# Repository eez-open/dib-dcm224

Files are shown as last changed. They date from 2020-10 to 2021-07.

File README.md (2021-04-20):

### Ownership and License
The contributors are listed in CONTRIB.TXT.

Licenses | OSHWA UID
--|--
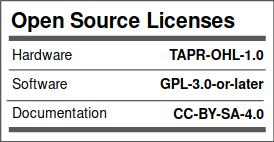
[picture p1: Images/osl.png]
osl
 | OSHW-HR000007 (https://certification.oshwa.org/hr000007.html)

### Overview

The EEZ DIB DCM224 Power module features dual sync buck converters based on [LT3763](https://www.analog.com/en/products/lt3763.html) with programmable output voltage, PWM dimming and current limit.

### r3B2 prototype

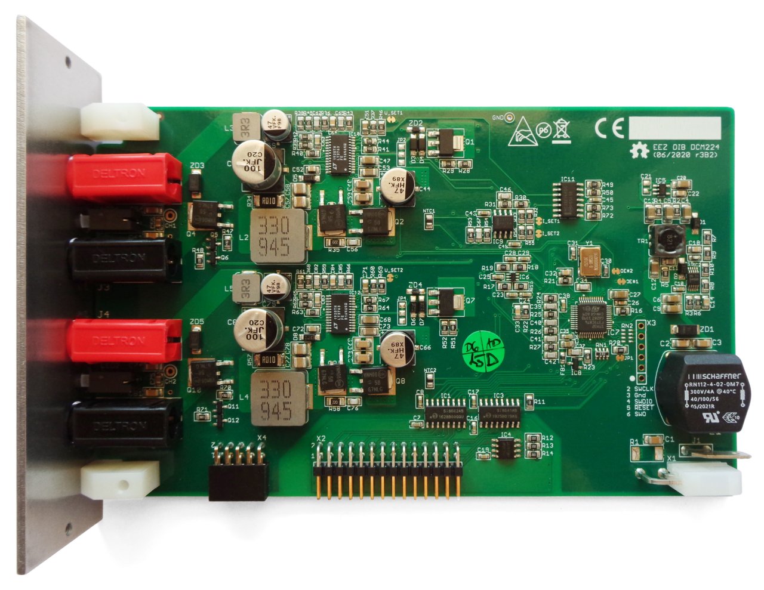
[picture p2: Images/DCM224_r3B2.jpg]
module


### Feature list
- On-board STM32F373 MCU
Power input: 48 Vdc (e.g. Mean Well LRS-150F-48)
- Combined max. output power: up to 155 W
- Separate control of each power outputs
- Voltage regulation (CV), 1 – 24 V. Voltage set resolution (_U_SET_): 12-bit, read resolution (_U_MON_): 15-bit
- Current regulation (CC), up to 4.9 A. Current set resolution (_I_SET_): 12-bit, read resolution (_I_MON_): 15-bit
- PWM LED dimming
- MCU generated two counterphase switching frequencies
- On-board power pre-regulator and bias power supply
- Output Enable (_OE_) and Constant Current mode (_CC_) LED indications
- Output LC filter for improved ripple and noise
- On-board 4 mm power output terminals with standard (19.05 mm) pitch
- Pass-thru connector for Vout- coupling with other DIB power modules
- Galvanically isolated SPI bus for communication with [MCU board](https://github.com/eez-open/modular-psu/tree/master/mcu)
- I2C EEPROM for storing board specific configuration and calibration parameters
- Dimensions: 155 x 95 mm, 4-layer PCB
- **CE certified design**

### Firmware repository

https://github.com/eez-open/dib-dcm224-fw  
The firmware download procedure is described in Chapter 13.2 of the [User Manual](https://www.envox.eu/eez-bench-box-3/bb3-user-manual/13-firmware-upgrade/#bb3_man_module_upgrade).

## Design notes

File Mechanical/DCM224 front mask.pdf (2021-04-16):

# DCM224

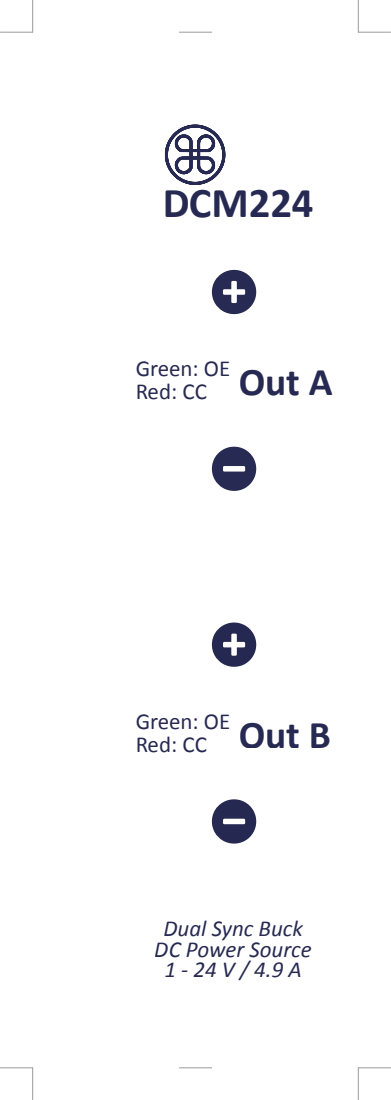
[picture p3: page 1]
Green: OE Red: CC; Out B; Out A

Dual Sync Buck
DC Power Source

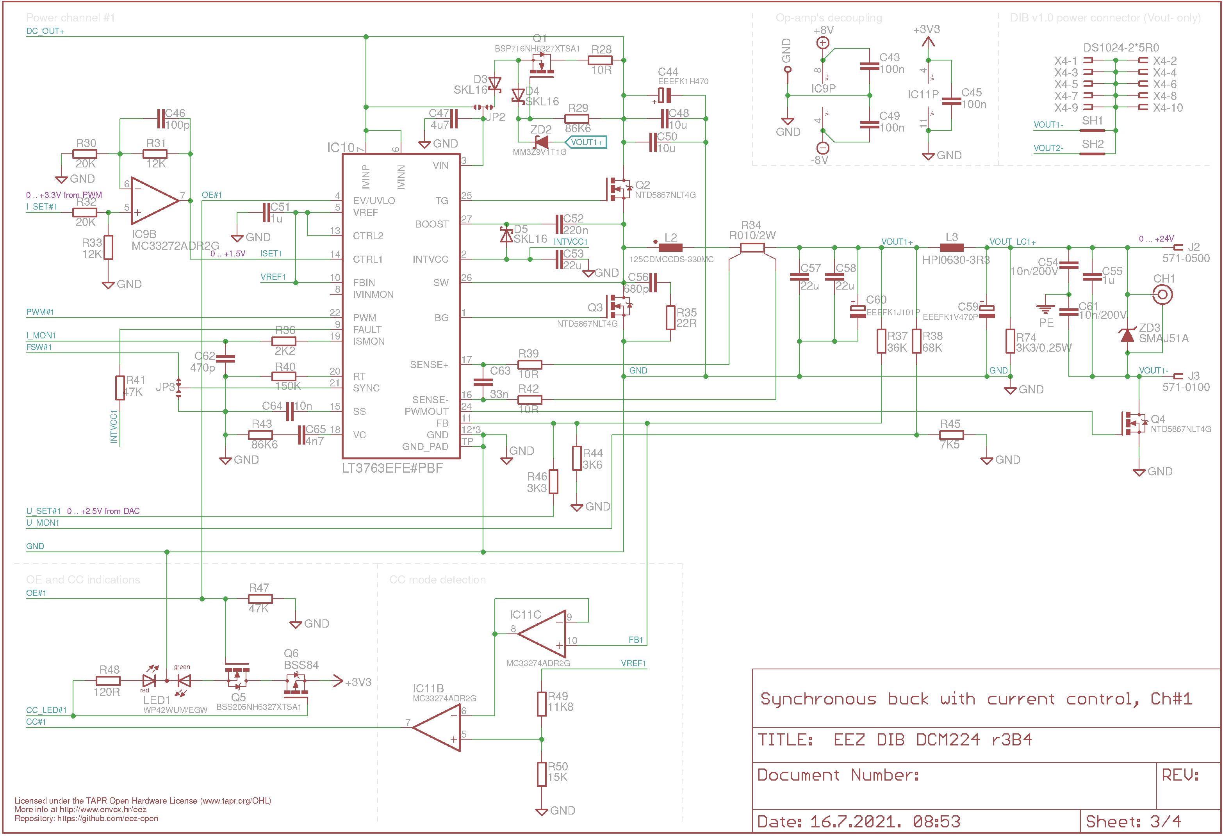
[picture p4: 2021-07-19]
EEZ DIB DCM224 r3B4 Sheet3of4.png

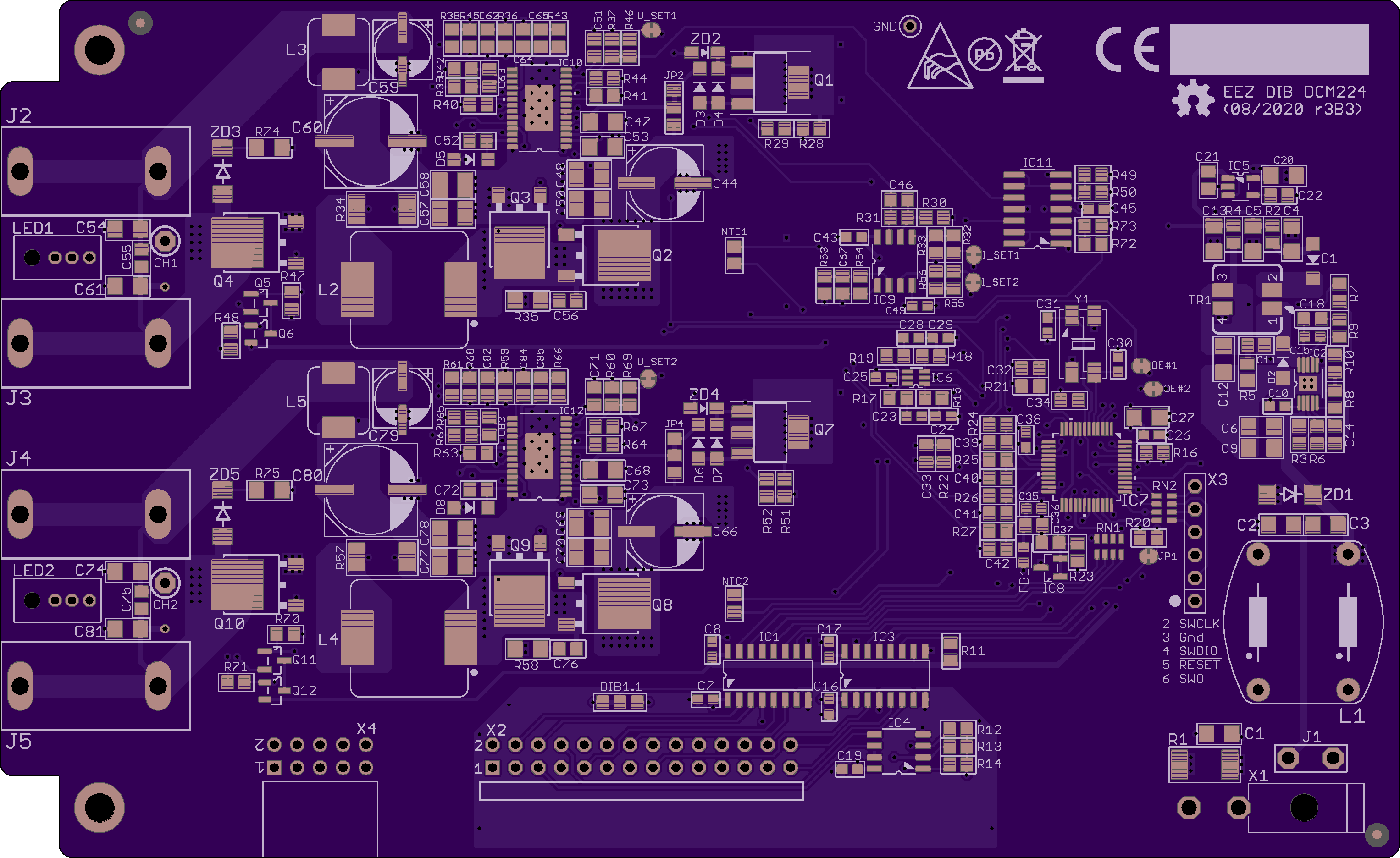
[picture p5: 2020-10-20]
Images/EEZ_DIB_DCM224_PCB_top.png

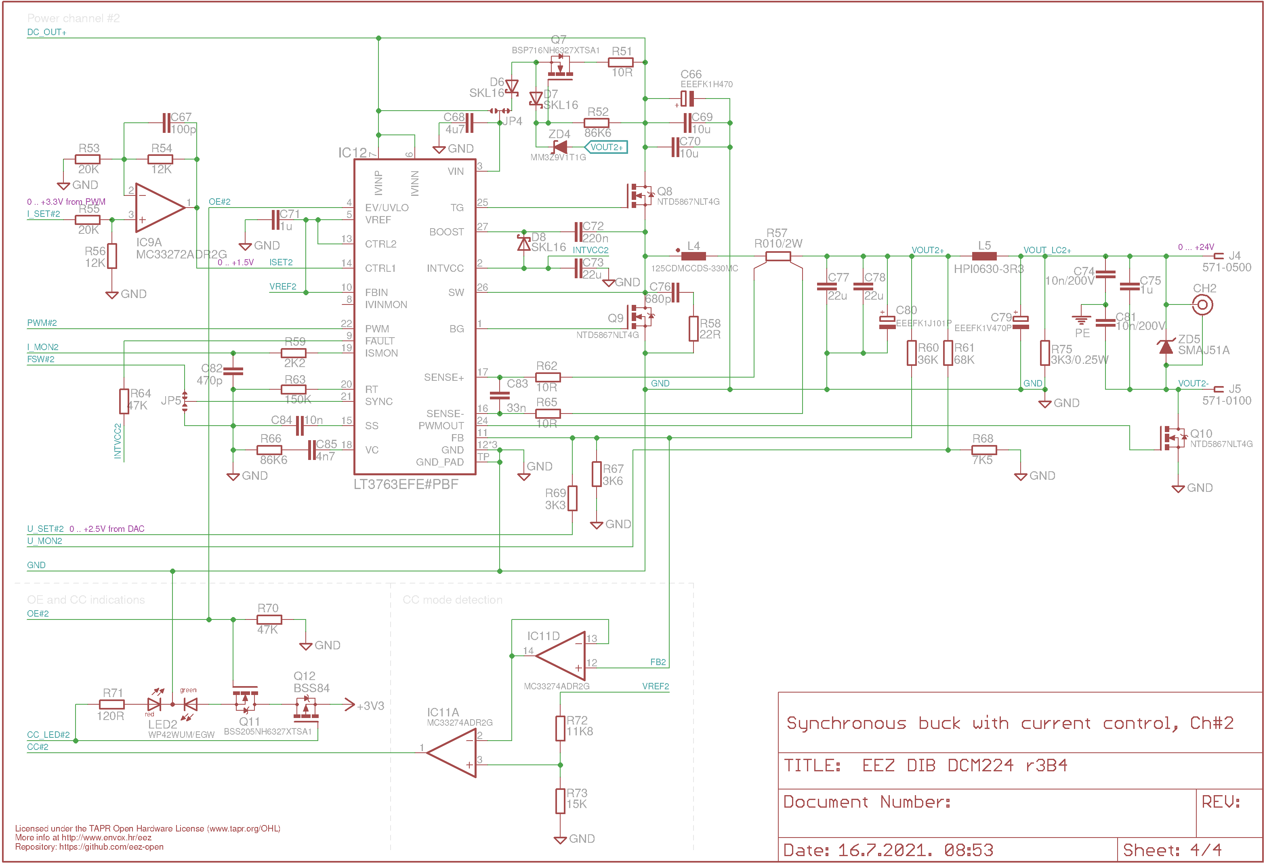
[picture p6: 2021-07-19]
EEZ DIB DCM224 r3B4 Sheet4of4.png

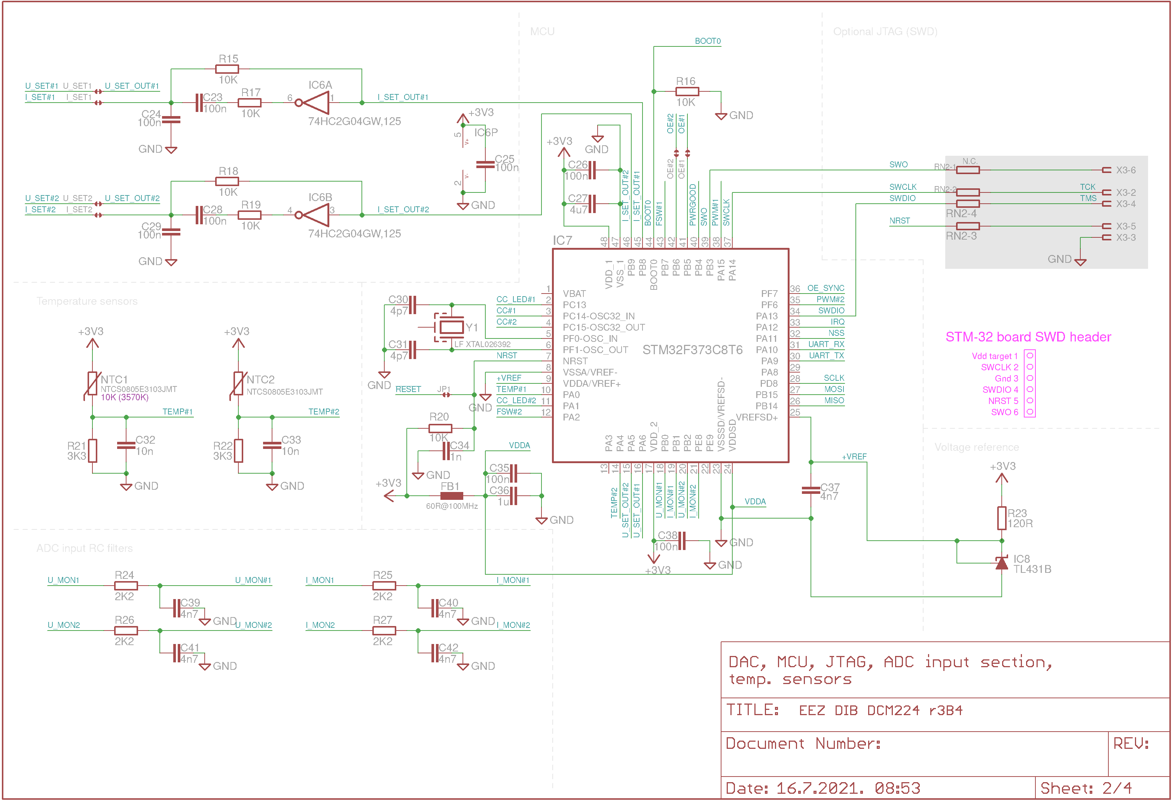
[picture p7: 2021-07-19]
EEZ DIB DCM224 r3B4 Sheet2of4.png

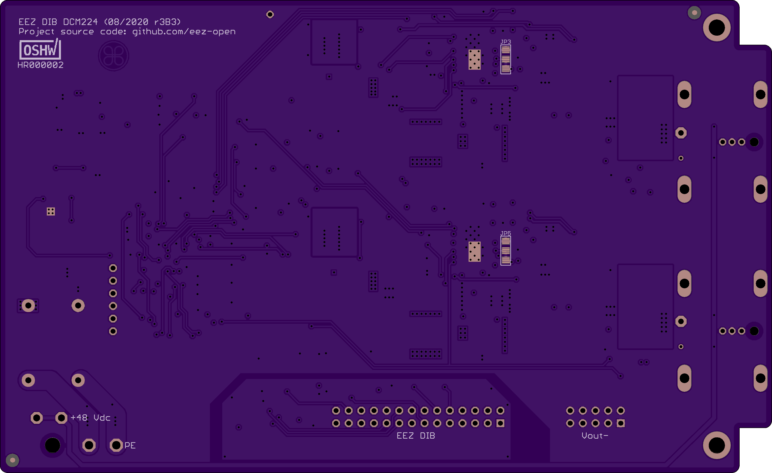
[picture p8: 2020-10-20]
Images/EEZ_DIB_DCM224_PCB_bottom.png

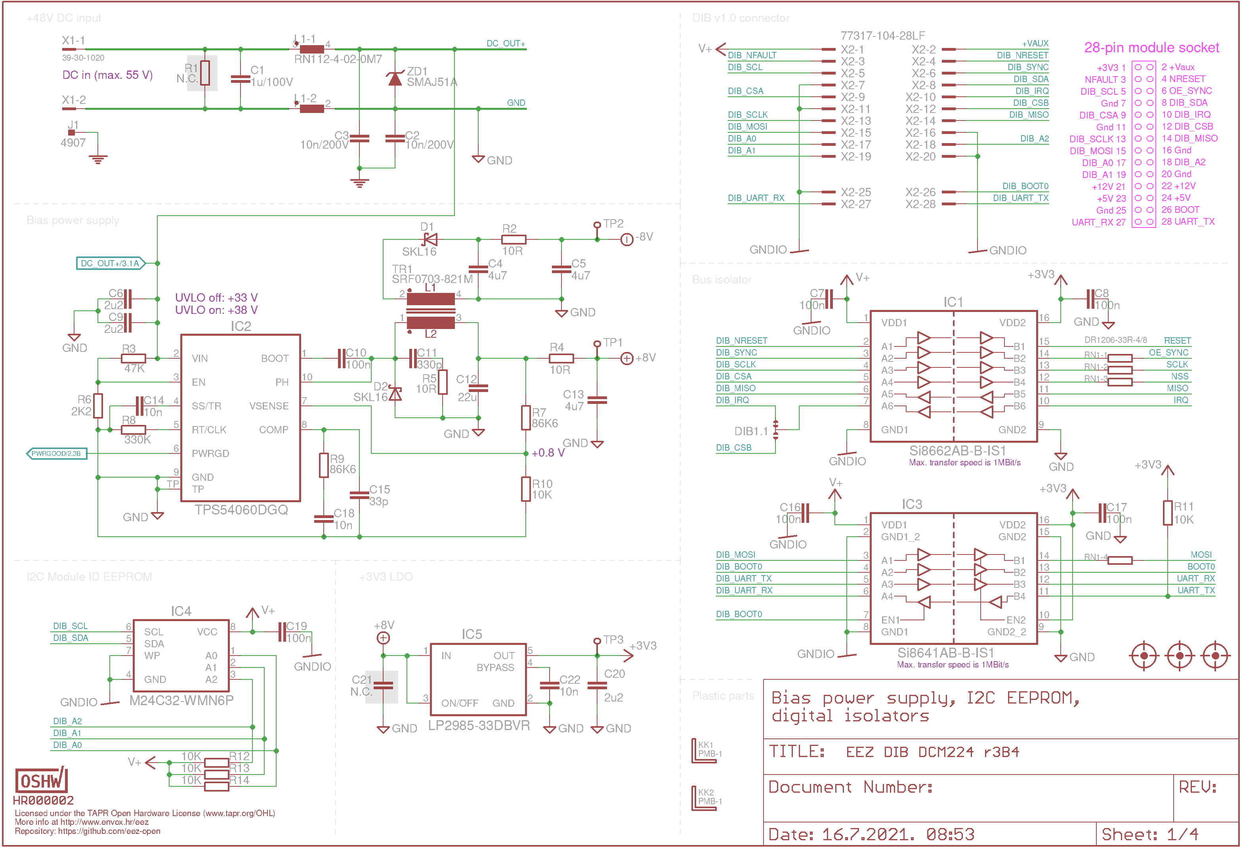
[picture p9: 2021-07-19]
EEZ DIB DCM224 r3B4 Sheet1of4.png

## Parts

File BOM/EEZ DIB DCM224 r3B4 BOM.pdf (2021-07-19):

EEZ DIB DCM224 BOM (r3B4, 2021-07-19) Project source code at https://github.com/eez-open/modular-psu
Farnell / Element14 Unit price # Qty Part name Package Reference designator Code Part Number MOQ € | Digi-Key Unit price Part Number MOQ € | Mouser Unit price Part Number MOQ €
| | 810-C3216X7R2A105 M
C0805C331J5GAC TU | | 80-C0805C331J5G
| | 963-LMK316ABJ226 ML-T
C14, C18, C22, C32, C33, VJ0805Y103JXXP C64, C84 W1BC | | 710-885012207122
| | C0805C330K5G ACTU 603-C1206KRX7RAB B103
C30, C31 MC0603N4R7C500 CT | | 710-885012006049
| | 710-885012007040
VJ0805Y105KXXT W1BC | | 603-CC805MKX7R7B B105
| | 810-C2012C0G1H47 2J-1
C3216X7R1E475K 160AC | | 963-EMK316B7475M L-T
| | FK1H470P
C46, C67 C0805C101JAGAC TU | | 80-C0805C101K5G
| | 810-C3216X7R1HK1 60AC
MC0805B224J250 CT | | 963-EMK212B7224K G-T
| | 710-885012207085
C57, C58, C77, C78 MC1210X226K250 CT | | 603-CC121KKX7R8B B226
| | FK1V470P
C1206C225K5REC TU | | 80-C1206C225M5R ECLR
1 | 1 1u/100V | 1206 | C1 | 2579026 | 0,635 | 5 | 311-1948-6-ND | 0,271 | 10 | 0,227 10
2 | 1 330p | C0G, 0805 | C11 | 1414686 | 0,054 10 | 1276-1189-1-ND | 0,049 | 10 | 0,036 10
3 | 3 22u | 1206, 10V | C12, C53, C73 | 2112754 | 0,616 | 5 | 1276-1287-1-ND | 0,265 | 10 | 0,155 10
4 | 7 10n | 0805 | 2896555 | 0,065 10 | 490-7194-1-ND | 0,017 | 10 | 0,036 10
5 | 1 33p | C0G, 0603 | C15 | 1759197 | 0,042 10 | 1276-1105-1-ND | 0,048 | 10 | 0,036 10
6 | 6 10n/200V | 1206 | C2, C3, C54, C61, C74, C81 2812560 | 885342207005 | 0,078 | 5 | 311-4491-1-ND | 0,150 | 10 | 0,129 10
7 | 2 4p7 | C0G, 0603 | 2627469 | 0,329 10 | 311-1740-1-ND | 0,054 | 10 | 0,072 10
8 | 1 1n | 0805 | C34 | 2896470 | 0,044 10 | 732-7858-1-ND | 0,055 | 10 | 0,052 10
9 | 5 1u | 0805 | C36, C51, C55, C71, C75 | 2896566 | 0,084 | 5 | 587-1283-1-ND | 0,090 | 10 | 0,062 10
10 | 7 4n7 | C0G, 0805 | 1828942 | 0,184 10 | 732-12255-1-ND | 0,162 | 10 | 0,072 10
11 | 6 4u7 | 1206 | C4, C5, C13, C27, C47, C68 1907356 | 0,240 | 5 | 1276-2970-1-ND | 0,199 | 10 | 0,129 10
12 | 2 EEEFK1H470 | | 9695931 | EEEFK1H470P | 0,419 | 1 | PCE3815CT-ND | 0,590 | 1 | 0,524 | 1
13 | 2 100p | C0G, 0805 | 2896861 | 0,023 10 | 399-15000-1-ND | 0,019 | 10 | 0,032 10
14 | 4 10u | 1210, 50V | C48, C50, C69, C70 | 2672214 | 0,684 | 5 | 1276-6736-1-ND | 0,184 | 10 | 0,597 10
15 | 2 220n | 0805 | C52, C72 | 2320828 | 0,087 | 5 | 1276-6477-1-ND | 0,520 | 10 | 0,059 10
16 | 2 680p | 0805 | C56, C76 | 2524913 | 0805B681K500CT | 0,049 10 | 1276-2538-1-ND | 0,049 | 10 | 0,036 10
17 | 4 22u | 1210, 25V | 2320935 | 1,490 | 1 | 1276-3373-1-ND | 0,369 | 10 | 0,777 10
18 | 2 | C59, C79 | 9695850 | | 0,368 | 1 | PCE3842CT-ND | 0,460 | 1 | 0,445 | 1
19 | 3 2u2 | 1206, 50V | C6, C9, C20 | 2991428 | 0,181 | 5 | 1276-2723-1-ND | 0,132 | 10 | 0,106 10
20 | 2 EEEFK1J101P | C60, C80 | 9696040 | EEEFK1J101P | 1,020 | 1 | PCE3819CT-ND | 0,780 | 1 | 0,690 | 1

C1206X105K1RAC
AUTO

MC1206X226M100
CT

MC0805N330J500
CT

VJ0805A102JXAC
W1BC

C37, C39, C40, C41, C42,
C65, C85

GRM2165C1H472J
A01D
Ø8mm, low ESR | C44, C66 | 667-EEE-

GRT31CR61H106
KE01L
EEEFK1V470P | Ø8mm, low ESR | EEEFK1V470P | 667-EEE-
Ø10mm, low ESR | 667-EEE- FK1J101P

# Qty Part name | RS Components | TME | Technology | Price calculation for 1 set

Unit price Code Part Number MOQ € | Unit price Code / Part Number MOQ € | THT SMD | | | Line Cost €

1 1 1u/100V

2 1 330p

3 3 22u

4 7 10n

5 1 33p

6 6 10n/200V

7 2 4p7

8 1 1n

9 5 1u

10 7 4n7

11 6 4u7

12 2 EEEFK1H470

13 2 100p

14 4 10u

15 2 220n

16 2 680p

17 4 22u

18 2

19 3 2u2

20 2 EEEFK1J101P

EEEFK1V470P

136-4396 | 0,294 50 | - | 1 | Mouser | 0,227 € | 1 | 0,227
176-3198 | 0,037 200 | CL21C331JBANNNC | 0,029 100 | 1 | TME | 0,029 € | 1 | 0,029
172-1532 | 0,095 50 | CL31A226MOCLNNC | 0,083 100 | 3 | TME | 0,083 € | 3 | 0,250
464-6672 | 0,026 50 | CC0805KRX7R9103 | 0,027 100 | 7 | Digikey | 0,017 € | 7 | 0,119
264-4264 | 0,069 25 | CL21C330JBANNNC | 0,015 100 | 1 | TME | 0,015 € | 1 | 0,015
669-8647 | 0,128 25 | 0,019 100 | 6 | TME | 0,019 € | 6 | 0,114
298-9315 | 0,024 25 | CL10C4R7CB8NNNC | 0,024 100 | 2 | RS | 0,024 € | 2 | 0,048
723-6408 | 0,031 100 | CL21C102JBCNNNC | 0,026 100 | 1 | TME | 0,026 € | 1 | 0,026
451-5770 | 0,028 25 | CL21B105KOFNNNE | 0,010 100 | 5 | TME | 0,010 € | 5 | 0,052
741-4529 | 0,056 100 | 0,021 100 | 7 | TME | 0,021 € | 7 | 0,147
691-1221 | 0,232 25 | 0,381 10 | 6 | Mouser | 0,129 € | 6 | 0,774
537-0590 EEEFK1H470P | 0,510 | 5 | EEEFK1H470P | 0,183 | 5 | 2 | TME | 0,183 € | 2 | 0,366
461-3997 | 0,030 50 | CL21C101JBANNNC | 0,026 100 | 2 | Digikey | 0,019 € | 2 | 0,038
103-4163 | 0,236 20 | CL31A106KBHNNNE | 0,546 10 | 4 | Digikey | 0,184 € | 4 | 0,736
103-4126 | 0,039 50 | CL21B224KAFNNNE | 0,022 100 | 2 | TME | 0,022 € | 2 | 0,044
- | CL21C681JBCNNNC | 0,048 100 | 2 | Mouser | 0,036 € | 2 | 0,072
766-1182 | 0,343 10 | CL32A226KAJNNNE | 0,158 10 | 4 | TME | 0,158 € | 4 | 0,632
537-0657 EEEFK1V470P | 0,422 | 1 | EEEFK1V470P | 0,130 | 5 | 2 | TME | 0,130 € | 2 | 0,260
184-3509 | 0,151 10 | CL31B225KBHNNNE | 0,029 50 | 3 | TME | 0,029 € | 3 | 0,086
708-3623 EEEFK1J101P | 0,676 | 5 | EEEFK1J101P | 0,321 | 5 | 2 | TME | 0,321 € | 2 | 0,642

Best
Supplier

Lowest
unit price
€

Order
Qty

12061C105KAT
2A

0805N331J500C
T
LMK316ABJ226
KL

08055C103KAT 2A

| VJ1206Y103KXCTW1 BC

C0603C479C5G ACTU

C0805C330J5G
ACTU
CC1206KRX7R
ABB103

GRM2195C1H1
02JA01D
C0805C105K4R ACTU
| GRM2165C1H472JA0 1D
C1206C475K3R ACTU | GCM31CR71E475KA5 5L

C2012C0G1H47
2J060AA

CC0805JRNP09
BN101
UMK316BBJ106
KL-T

UMK212B7224K
G-T

CL32A226KAJN
NNE

UMK316B7225K
LHT

# Qty Part name Package Reference designator Code Part Number MOQ € | Part Number Unit price MOQ € | Part Number Unit price MOQ Unit price €

MC0805N471J500 CT | | 710-885012007038
| | 710-885012207069
C7, C8, C10, C16, C17, C19, C0603C104K4RAC C23, C24, C25, C26, C28, 7081 C29, C35, C38, C43, C45, C49 | | 80-C0603C104M4R
| RB160MM-60CT-ND | 755-RB160MM-60TR
BLM18AG102SN1 D | | 81-BLM18AG102SH 1D
| SI8662AB-B-IS1-ND | 634-SI8662AB-B-IS1
| LT3763EFE#PBF -ND | 584-LT3763EFE#PBF
| MC33274ADR2G OSCT-ND | 863-MC33274ADR2G
TPS54060DGQ | | 595-TPS54060DGQR
| SI8641AB-B-IS1-ND | 634-SI8641AB-B-IS1
| | 511-M24C32-WMN6P
| | 595-LP2985-33DBVR
74HC2G04GW,125 74HC2G04GW,125 | | 771-HC2G04GW125
| | STM32F373C8T 6
| | 771-TL431BIDBZR21 5
| MC33272ADR2G OSCT-ND | 863-MC33272ADR2G

THT, PCB terminal; 4.8mm

21 | 2 470p | 0805 | C62, C82 | 1759217 | 0,061 10 | 732-7837-1-ND | 0,059 | 10 | 0,056 10
22 | 2 33n | 0805 | C63, C83 | 2627479 | 0,046 10 | 1276-1796-1-ND | 0,057 | 10 | 0,036 10
23 | 17 100n | 0603 | 2522597 | 0,011 10 | 490-4774-1-ND | 0,029 100 | 0,007 100
24 | 8 SKL16 | SOD-123 | 2673070 | RB160MM-60TR | 0,282 | 5 | 0,264 | 10 | 0,233 10
25 | 1 BLM18AG102SH1D | 0603 | FB1 | 1515671 | 0,053 10 | 490-7809-1-ND | 0,081 | 10 | 0,063 10
26 | 1 Si8662AB-B-IS1 | SOIC-16 | IC1 | 2423351 | SI8662AB-B-IS1 | 1,850 | 1 | | 1,920 | 1 | 1,760 | 1
27 | 2 LT3763EFE#PBF | TSSOP-28 | IC10, IC12 | - | | | | | 4,950 | 1 | 4,830 | 1
28 | 1 MC33274ADR2G | SOIC-14 | IC11 | 2531387 | MC33274ADR2G | 1,010 | 1 | | 1,190 | 1 | 1,020 | 1
29 | 1 | MSOP-10 | IC2 | 1710820 | TPS54060DGQ . | 3,030 | 1 | 296-37148-1-ND | 2,630 | 1 | 2,490 | 1
30 | 1 Si8641AB-B-IS1 | SOIC-16 | IC3 | 2423288 | Si8641AB-B-IS1 | 1,460 | 1 | | 1,530 | 1 | 1,410 | 1
31 | 1 M24C32-WMN6P | SOIC-8 | IC4 | 1224413 | M24C32-WMN6P | 0,212 | 5 | - | | | 0,210 | 1
32 | 1 | SOT-23-5 | IC5 | 1053660 | | 0,610 | 1 | 296-18476-1-ND | 0,540 | 1 | 0,507 | 1
33 | 1 | IC6 | 2777732 | 0,283 | 5 | 1727-6045-1-ND | 0,274 | 10 | 0,248 10
34 | 1 | LQFP-48 | IC7 | 2333274 | | 4,420 | 1 | 497-13306-ND | 3,940 | 1 | 3,840 | 1
35 | 1 TL431BIDBZR | SOT-23 | IC8 | 2095470 | TL431BCDBZR | 0,310 | 5 | 296-18866-1-ND | 0,305 | 10 | 0,342 10
36 | 1 MC33272ADR2G | SOIC-8 | IC9 | 2531389 | MC33272ADR2G | 0,854 | 1 | | 0,910 | 1 | 0,865 | 1
37 | 1 4907 | J1 | - | 36-4907-ND | 0,260 | 1 | 534-4907 | 0,257 | 1
38 | 2 571-0500 | J2, J4 | 1101127 | 571-0500-01 | 1,720 | 5 | - | 164-6219 | 2,040 | 1
39 | 2 571-0100 | J3, J5 | 1101128 | 571-0100-01 | 1,740 | 5 | - | 164-6218 | 1,840 | 1
40 | 1 RN112-4-02-0M7 | | L1 | - | | | | 817-2100-ND | 1,560 | 1 | 1,400 | 1
41 | 2 125CDMCCDS-330MC | | L2, L4 | 2211631 | 7443551331 | 3,930 | 1 | 308-2568-1-ND | 1,510 | 1 | 1,590 | 1
42 | 2 HPI0630-3R3 | | L3, L5 | 1741325 | | 1,940 | 5 | | 0,510 | 1 | 0,510 | 1
43 | 2 WP42WUM/EGW | | LED1, LED2 | - | | | | 754-1718-ND | 0,930 | 1 | 0,926 | 1

MC0805B333K250
CT

D1, D2, D3, D4, D5, D6, D7, D8

LP2985-33DBVR | LP2985A- 33DBVTE4 .
STM32F373C8T6 | STM32F373C8T6 | 511-

THT, Ø4 mm terminal; red
THT, Ø4 mm terminal; black
| | 631-RN112-4-02-0M7
Power inductor | | 851-125CDMCCDS3 30MC
| 445-180834-1-ND | 810-VLS6045AF-3R3N
THT, dual (green/red) 3 mm LED | | 604-WP42WUM/EG W

THT, Current-compensated
Choke
Power inductor | IHLP2020CZER3R 3M11

# Qty Part name

21 2 470p

22 2 33n

23 17 100n

24 8 SKL16

25 1 BLM18AG102SH1D

26 1 Si8662AB-B-IS1

27 2 LT3763EFE#PBF

28 1 MC33274ADR2G

29 1

30 1 Si8641AB-B-IS1

31 1 M24C32-WMN6P

32 1

33 1

34 1

35 1 TL431BIDBZR

36 1 MC33272ADR2G

37 1 4907
38 2 571-0500
39 2 571-0100
40 1 RN112-4-02-0M7

41 2 125CDMCCDS-330MC

42 2 HPI0630-3R3

43 2 WP42WUM/EGW

TPS54060DGQ

LP2985-33DBVR

74HC2G04GW,125

STM32F373C8T6

Code Part Number MOQ € | Code / Part Number Unit price MOQ € | THT SMD | Line Cost € Unit price
| 0805CG471J9B B | CC0805JRNPO9BN47 1

Best
Supplier

Lowest
unit price
€

Order
Qty
378-700 | 0,040 25 | | 0,024 100 | 2 | TME | 0,024 € | 2 | 0,048
135-6639 | 0,021 100 | CC0805KRX7R9333 | 0,016 100 | 2 | TME | 0,016 € | 2 | 0,032
393-6952 | 0,069 25 | CL10B104KA8NNNC | 0,098 100 | 17 | Mouser | 0,007 € 17 | 0,119
124-6774 RB160MM-60TR | 0,230 40 | SKL16-DIO | 0,105 | 5 | 8 | TME | 0,105 € | 8 | 0,840
839-0803 | 0,043 100 | BLM18AG102SH1D | 0,016 50 | 1 | TME | 0,016 € | 1 | 0,016
823-2062 Si8662AB-B-IS1 | 1,870 | 5 | - | | | 1 | Mouser | 1,760 € | 1 | 1,760
- | | | | | | 2 | Mouser | 4,830 € | 2 | 9,660
773-7787 | 1,010 | 2 | MC33274ADR2G | 0,740 | 1 | 1 | TME | 0,740 € | 1 | 0,740
698-9079 TPS54060DGQ | 2,680 | 1 | - | | | 1 | Mouser | 2,490 € | 1 | 2,490
823-2000 Si8641AB-B-IS1 | 1,496 | 5 | - | | | 1 | Mouser | 1,410 € | 1 | 1,410
686-2453 | 0,180 25 | M24C32-WMN6P | 0,165 | 3 | 1 | TME | 0,165 € | 1 | 0,165
660-6733 LP2985-33DBVT | 0,737 | 1 | LP2985-33DBVR | 0,362 | 1 | 1 | TME | 0,362 € | 1 | 0,362
153-2919 | 0,235 50 | 74HC2G04GW.125 | 0,138 | 5 | 1 | TME | 0,138 € | 1 | 0,138
795-9164 | 2,060 | 1 | - | | | 1 | RS | 2,060 € | 1 | 2,060
797-4826 | 0,259 | 2 | TL431BIDBZR | 0,237 | 3 | 1 | TME | 0,237 € | 1 | 0,237
773-7778 | 0,865 | 1 | MC33272ADR2G | 0,570 | 1 | 1 | TME | 0,570 € | 1 | 0,570
- | 61-1537-11/0031 | 0,049 10 | 1 | TME | 0,049 € | 1 | 0,049
103-6511 571-0500 | 1,216 | 5 | 571-0500 | 0,620 | 3 | 2 | TME | 0,620 € | 2 | 1,240
103-6527 571-0100 | 1,334 | 5 | 571-0100 | 0,620 | 3 | 2 | TME | 0,620 € | 2 | 1,240
- | | | - | | | 1 | Mouser | 1,400 € | 1 | 1,400
- | | | - | | | 2 | Digikey | 1,510 € | 2 | 3,020
- | | | HPI0630-3R3 | 0,335 | 1 | 2 | TME | 0,335 € | 2 | 0,670
- | | | L-42WUM/1EGWT | 0,501 | 1 | 2 | TME | 0,501 € | 2 | 1,002

08051C333KAT
2A
VJ0603Y104KXJ
AT

BLM18AG102S
H1D

MC33274ADR2
G

M24C32-
WMN6P

74HC2G04GW,1
25
STM32F373C8T
6

TL431BIDBZR,2
15

MC33272ADR2
G

# Qty Part name Package Reference designator Code Part Number MOQ € | Part Number Unit price MOQ € | Part Number Unit price MOQ Unit price €

| | 594-2381-615-53103
BSP716NH6327XTSA1 BSP716NH6327XT SA1 | BSP716NH6327 XTSA1CT-ND | 726-BSP716NH6327 XTSA
| NTD5867NLT4G OSCT-ND | 863-NTD5867NLT4G
BSS205NH6327XTSA1 Q5, Q11 BSS205NH6327XT SA1 | BSS205NH6327 XTSA1CT-ND | BSS205NH6327 XTSA1
| BSS84PH6433X TMA1CT-ND | 726-BSS84PH6327X TSA2
R10, R11, R12, R13, R14, RC0805FR-R15, R16, R17, R18, R19, 0710KL R20 | 311-10.0KCRCT-ND | 603-RC0805FR-0710KL
| 311-10.0CRCT-ND | 71-CRCW080510R0 FKEAC

MCWR08X3301FT L

| RMCF0805FT12 0RCT-ND | 71-CRCW0805120R FKEAC
MCWR08X4702FT L | RHM47KKCT-ND | 603-RC0805FR-0747KL
| | RCG080520K0F KEA
MCWR08X1202FT L | | 71-CRCW080512K0 FKEA
| MCS3264R010F ERCT | 754-KRL3264ECR01 0FT1
| 118-CRM1206-FX-22R0ELFCT-ND | 603-RC1206JR-7W22RL
| 311-36.0KCRCT-ND | 603-RT0805FRE0736 KL
MCWR08X6802FT L | | 603-RT0805FRE0768 KL
| | 279-CRGCQ0805F15 0K
MCWR08X3601FT L | RMCF0805FT3K 60CT-ND | 603-RT0805FRE073 K6L
44 | 2 NTCS0805E3103JMT | NTC 0805 | NTC1, NTC2 | 2103177 | 0,399 10 | BC2292CT-ND | 0,490 | 1 | 0,353 10
45 | 2 | SOT-223 | Q1, Q7 | 2803380 | 0,378 | 5 | 0,372 | 10 | 0,333 10
46 | 6 NTD5867NLT4G | DPAK | Q2, Q3, Q4, Q8, Q9, Q10 | 1879964 | NTD5867NLT4G | 0,493 10 | 0,458 | 10 | 0,430 10
47 | 2 | SOT-23 | 2480648 | 0,257 | 5 | 0,274 | 10 | 0,236 10
48 | 2 BSS84P | SOT-23 | 1056526 | 0,224 | 5 | 0,314 | 10 | 0,196 10
49 | 11 10K | 0805 | 9237755 | 0,022 10 | 0,039 | 10 | 0,014 10
50 | 9 10R | 0805 | 2447556 | 0,007 10 | 0,064 | 10 | 0,047 10
51 | 4 3K3 | 0805 | R21, R22, R46, R69 | 2447651 | 0,010 10 | A129755CT-ND | 0,045 | 10
52 | 3 120R | 0805 | R23, R48, R71 | 2447561 | 0,009 10 | 0,020 | 10 | 0,037 10
53 | 5 47K | 0805 | R3, R41, R47, R64, R70 | 2447664 | 0,009 10 | 0,036 | 10 | 0,014 10
54 | 4 20K | 0805 | R30, R32, R53, R55 | 2447603 | 0,009 10 | A126349CT-ND | 0,047 | 10 | 0,034 50
55 | 4 12K | 0805 | R31, R33, R54, R56 | 2447563 | 0,010 10 | A126337CT-ND | 0,047 | 10 | 0,058 10
56 | 2 R010/2W | 2512 | R34, R57 | 2709394 | 0,779 10 | 0,568 | 10 | 0,590 10
57 | 2 22R/0.5W | 1206 | R35, R58 | 2331841 | CRGH1206J22R | 0,035 10 | 0,106 | 10 | 0,103 10
58 | 2 36K | 0805 | R37, R60 | 2447643 | 0,007 10 | 0,037 | 10 | 0,050 10
59 | 2 68K | 0805 | R38, R61 | 2447706 | 0,007 10 | A126382CT-ND | 0,045 | 10 | 0,058 10
60 | 2 150K | 0805 | R40, R63 | 2447573 | 0,008 10 | A126340CT-ND | 0,045 | 10 | 0,038 10
61 | 2 3K6 | 0805 | R44, R67 | 2447652 | 0,010 10 | 0,010 100 | 0,017 100
62 | 2 7K5 | 0805 | R45, R68 | 2447722 | 0,007 10 | A126387CT-ND | 0,045 | 10 | 0,032 10

NTCS0805E3103J
MT
Q6, Q12 | BSS84PH6327XTS A2

R2, R4, R5, R28, R39, R42, R51, R62, R65

MCWR08X10R0FT
L

MCWR08X1200FT
L

MCWR08X2002FT
L

CRF2512-FZ-R010ELF

MCWR08X3602FT
L

MCWR08X1503FT
L

MCWR08X7501FT
L

652-CR0805FX-7501ELF

# Qty Part name

44 2 NTCS0805E3103JMT

45 2

46 6 NTD5867NLT4G

47 2

48 2 BSS84P

49 11 10K

50 9 10R

51 4 3K3

52 3 120R

53 5 47K

54 4 20K

55 4 12K

56 2 R010/2W

57 2 22R/0.5W

58 2 36K

59 2 68K

60 2 150K

61 2 3K6

62 2 7K5

BSP716NH6327XTSA1

BSS205NH6327XTSA1

Code Part Number MOQ € | Code / Part Number Unit price MOQ € | THT SMD | Line Cost € Unit price

Best
Supplier

Lowest
unit price
€

Order
Qty
179-3950 | 0,250 250 | NTCS0805E3103JMT | 0,113 15 | 2 | TME | 0,113 € | 2 | 0,226
- | | | | 0,201 | 3 | 2 | TME | 0,201 € | 2 | 0,402
719-2901 NTD5867NLT4G | 0,524 | 5 | NTD5867NLT4G | 0,310 | 3 | 6 | TME | 0,310 € | 6 | 1,860
892-2374 | 0,108 100 | 0,097 10 | 2 | TME | 0,097 € | 2 | 0,194
- | BSS84P | 0,060 10 | 2 | TME | 0,060 € | 2 | 0,120
125-1189 CRG0805F10K | 0,002 100 | 0805S8F1002T5E | 0,014 100 | 11 | RS | 0,002 € 11 | 0,022
223-0152 CRG0805F10R | 0,019 50 | 0805S8F100JT5E | 0,015 100 | 9 | Farnell | 0,007 € | 9 | 0,059
223-0499 CRG0805F3K3 | 0,027 50 | 805S8F3301T5E | 0,015 100 | 4 | Farnell | 0,010 € | 4 | 0,039
223-0304 CRG0805F120R | 0,035 50 | 0805S8F1200T5E | 0,022 100 | 3 | Farnell | 0,009 € | 3 | 0,028
679-1434 | 0,036 50 | RC0805FR-0747K | 0,022 100 | 5 | Farnell | 0,009 € | 5 | 0,047
679-1077 | 0,038 50 | RC0805FR-0720K | 0,035 100 | 4 | Farnell | 0,009 € | 4 | 0,038
223-0578 CRG0805F12K | 0,020 50 | SMD0805-12K-1% | 0,014 100 | 4 | Farnell | 0,010 € | 4 | 0,040
693-4381 | 0,496 10 | LRP12FTWRR010 | 0,151 10 | 2 | TME | 0,151 € | 2 | 0,302
- | HP06W2J0220T5E | 0,042 50 | 2 | Farnell | 0,035 € | 2 | 0,070
679-1314 | 0,004 50 | 0805S8F3602T5E | 0,015 100 | 2 | RS | 0,004 € | 2 | 0,008
679-1620 | 0,038 50 | 0805S8F6802T5E | 0,015 100 | 2 | Farnell | 0,007 € | 2 | 0,014
223-0714 CRG0805F150K | 0,023 50 | 0805S8J0154T5E | 0,013 100 | 2 | Farnell | 0,008 € | 2 | 0,016
865-4425 ERJU06F3601V | 0,039 50 | 0805S8F3601T5E | 0,007 100 | 2 | TME | 0,007 € | 2 | 0,014
679-1686 | 0,038 50 | 0805S8F7501T5E | 0,015 100 | 2 | Farnell | 0,007 € | 2 | 0,014

NTCS0805E310
3JMT
BSP716NH6327XTSA
1

BSS205NH6327
XTSA1

BSS205NH6327XTSA
1

CRCW080547K
0FKEA
CRCW080520K
0FKEA

CRA2512-FZ-R010ELF

CRCW080536K
0FKEA

CRCW080568K
0FKEA

CRCW08057K5
0FKEA

# Qty Part name Package Reference designator Code Part Number MOQ € | Part Number Unit price MOQ € | Part Number Unit price MOQ Unit price €

CRCW080511K8F KEA. | 311-11.8KCRCT-ND | 603-RC0805FR-0711K8L
| | 71-CRCW080515K0 FKEBC
R6, R24, R25, R26, R27, RC0805FR-R36, R59 072K2L | 311-2.20KCRCT-ND | 603-RC0805FR-072K2L
| 311-86.6KCRCT-ND | 603-RT0805FRE0786 K6L
MCWR12X3301FT L | RC1206FR-073K3L | 71-CRCW12063K30 FKEAC
| | 652-CR0805FX-3303ELF
| CAY16-330J4LFCT-ND | 652-CAY16-330J4LF
| SRF0703-821MCT-ND | 652-SRF0703-821M

THT, Minifit Jr. 2-pin, right angle

| | 649-77317-104-28LF
THT, 10-pin 0.1" receptacle right angled | | 710-613010243121
| | 449-LFXTAL026392B ULK
ZD1, ZD3, ZD5 | SMAJ51ALFCT-ND
63 | 2 11K8 | 0805 | R49, R72 | 2138981 | 0,040 10 | 0,037 | 10 | 0,010 100
64 | 2 15K | 0805 | R50, R73 | 1099808 | WCR0805-15KFI | 0,019 10 | A126341CT-ND | 0,041 | 10 | 0,013 10
65 | 7 2K2 | 0805 | 9237534 | 0,037 10 | 0,039 | 10 | 0,026 10
66 | 6 86K6 | 0805 | R7, R9, R29, R43, R52, R66 2303750RL ERJ6ENF8662V | 0,058 10 | 0,036 | 10 | 0,056 10
67 | 2 3K3, 0.25W | 1206 | R74, R75 | 2447514 | 0,014 10 | 0,090 | 10 | 0,069 10
68 | 1 330K | 0805 | R8 | 2447637 | 0,010 10 | A126361CT-ND | 0,046 | 10 | 0,013 10
69 | 1 DR1206-33R-4/8 | 1206 resistor array | RN1 | 1770128 | CAY16-330J4LF | 0,069 10 | 0,090 | 1 | 0,085 | 1
70 | 1 SRF0703-821M | 0703 | TR1 | 1852832 | SRF0703-821M | 0,827 | 1 | 0,900 | 1 | 0,681 | 1
71 | 1 39-30-1020 | X1 | 9732080 | 39-28-1023 | 0,367 | 1 | WM3800-ND | 0,530 | 1 | 538-39-28-1023 | 0,530 | 1
72 | 1 77317-104-28LF | X2 | - | | | | S2111EC-14-ND | 1,030 | 1 | | 1,540 | 1
73 | 1 DS1024-2*5R0 | X4 | 1841243 | 613010243121 | 0,910 | 1 | S9202-ND | 0,720 | 1 | | 0,950 | 1
74 | 1 LF XTAL026392 | Y1 | 1276696 | LFXTAL026392 | 1,250 | 1 | 1923-1009-ND | 0,850 | 1 | | 0,972 | 1
75 | 3 SMAJ51A | SMA | 2677667 | SMAJ51A | 0,144 | 5 | 0,370 | 1 | 652-SMAJ51A | 0,463 | 1
76 | 2 | SOD-323 | ZD2, ZD4 | 2463517 | MM3Z9V1T1G | 0,124 | 5 | 0,120 | 1 | 0,108 10

Not installed
1 N.C. | 0805 | C21
1 N.C. 2512 R1 2081875 ASC2512-4K7FT4 0,195 10 | A130729CT-ND 0,331 10 | 279-0,180 10 CRGP2512F4K7
| CAY16-330J4LFCT-ND | 652-CAY16-330J4LF

1 22-23-2061 THT X3

1 DR1206-33R-4/8 | 1206 resistor array | RN2 | 1770128 | CAY16-330J4LF | 0,069 10 | 0,090 | 1 | 0,085 | 1

Custom made components
1 PCB | 4-layer 145 x 95 mm, 1 oz. Cu thickness (MOQ: 5, incl. S&H)
| All prices are net prices (without VAT)

MCWR08X3303FT
L

THT, 28-pin 0.1" header right angled

16 MHz XTAL;
7.5x5.1x1.4mm
MM3Z9V1T1G | MM3Z9V1T1GO SCT-ND

863-
MM3Z9V1T1G

# Qty Part name

63 2 11K8

64 2 15K

65 7 2K2

66 6 86K6

67 2 3K3, 0.25W

68 1 330K

69 1 DR1206-33R-4/8

70 1 SRF0703-821M

71 1 39-30-1020

72 1 77317-104-28LF

73 1 DS1024-2*5R0

74 1 LF XTAL026392

75 3 SMAJ51A

76 2

Not installed
1 N.C.
1 N.C.

1 DR1206-33R-4/8

1

Custom made components
1 PCB

MM3Z9V1T1G

22-23-2061

Code Part Number MOQ € | Code / Part Number Unit price MOQ € | THT SMD | Line Cost € Unit price
| CRCW080511K 8FKEA

Best
Supplier

Lowest
unit price
€

Order
Qty
679-0847 | 0,036 50 | 0805S8F1182T5E | 0,014 100 | 2 | Mouser | 0,010 € | 2 | 0,020
223-0584 CRG0805F15K | 0,023 50 | SMD0805-15K | 0,013 100 | 2 | Mouser | 0,013 € | 2 | 0,026
679-1207 | 0,039 50 | 0805S8F2201T5E | 0,022 100 | 7 | TME | 0,022 € | 7 | 0,156
- | 0,025 100 | 6 | TME | 0,025 € | 6 | 0,150
223-2338 CRG1206F3K3 | 0,017 10 | 1206S4J0332T5E | 0,012 100 | 2 | TME | 0,012 € | 2 | 0,024
679-1272 | 0,038 50 | SMD0805-330K-1% | 0,015 100 | 1 | Farnell | 0,010 € | 1 | 0,010
522-5670 CAY16-330J4LF | 0,004 50 | DR1206-33R-4/8 | 0,009 100 | 1 | RS | 0,004 € | 1 | 0,004
- | - | 1 | Mouser | 0,681 € | 1 | 0,681
484-1883 39-28-102 | 0,354 | 5 | MX-39-30-1020 | 0,339 | 5 | 1 | TME | 0,339 € | 1 | 0,339
- | | | - | | | 1 | Digikey | 1,030 € | 1 | 1,030
826-7194 613010243121 | 0,950 | 1 | ZL263-10DG | 0,301 | 2 | 1 | TME | 0,301 € | 1 | 0,301
148-4357 LFXTAL026392 | 0,960 10 | 16.00M-12SM | 0,950 | 1 | 1 | Digikey | 0,850 € | 1 | 0,850
171-4238 SMAJ51A | 0,320 25 | SMAJ51A-LF | 0,201 | 3 | 3 | Farnell | 0,144 € | 3 | 0,432
802-4653 MM3Z9V1T1G | 0,039 200 | MM3Z9V1T1G | 0,020 25 | 2 | TME | 0,020 € | 2 | 0,041
11 | 205 | 41,52 €
| | | | 1 | Farnell | 0,000 € | 1 | 0,000
224-0424 35204K7JT | 1,370 10 | | 0,113 10 | 1 | TME | 0,113 € | 1 | 0,113
522-5670 CAY16-330J4LF | 0,004 50 | DR1206-33R-4/8 | 0,009 100 | 1 | RS | 0,004 € | 1 | 0,004
1 | Farnell | 0,000 € | 1 | 0,000
JLCPCB | 10,892 € | 1 | 10,892
| | | 10,89 €
| | Total | 52,42 €

CRCW08052K2 0FKEA

| CRCW080586K6FKTA BC

CRCW0805330
KFKEA

CRCW25124K70FKTH
BC

# | Qty | Part name | Package | Reference designator | Code | Part Number | MOQ | Part Number | MOQ | Part Number | MOQ Unit price

€

Unit price
€

Unit price
€

All resistors are 1% 0805 and all capacitors are X7R 0805 if not otherwise specified.

Please note that BOM does not contain ordering number for parts on reels or that which includes re-reeling fee (e.g. Farnell). Take also into account that total cost is higher because min. quantity (MOQ) for many parts is larger then what is needed for single unit.

# Qty Part name

Code Part Number MOQ € | Code / Part Number Unit price MOQ € | THT SMD | Line Cost € Unit price

Best
Supplier

Lowest
unit price
€

Order
Qty

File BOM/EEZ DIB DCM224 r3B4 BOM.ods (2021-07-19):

 |  |  |  |  | Farnell / Element14 |  |  |  | Digi-Key |  |  | Mouser |  |  | RS Components |  |  |  | TME |  |  | Technology |  | Price calculation for 1 set
# | Qty | Part name | Package | Reference designator | Code | Part Number | Unit price € | MOQ | Part Number | Unit price € | MOQ | Part Number | Unit price € | MOQ | Code | Part Number | Unit price € | MOQ | Code / Part Number | Unit price € | MOQ | THT | SMD | Best Supplier | Lowest unit price € | Order Qty | Line Cost €
1 | 1 | 1u/100V | 1206 | C1 | 2579026 | C1206X105K1RACAUTO | 0,635 | 5 | 311-1948-6-ND | 0,271 | 10 | 810-C3216X7R2A105M | 0,227 | 10 | 136-4396 | 12061C105KAT2A | 0,294 | 50 | - |  |  |  | 1 | Mouser | 0,227 € | 1 | 0,227
2 | 1 | 330p | C0G, 0805 | C11 | 1414686 | C0805C331J5GACTU | 0,054 | 10 | 1276-1189-1-ND | 0,049 | 10 | 80-C0805C331J5G | 0,036 | 10 | 176-3198 | 0805N331J500CT | 0,037 | 200 | CL21C331JBANNNC | 0,029 | 100 |  | 1 | TME | 0,029 € | 1 | 0,029
3 | 3 | 22u | 1206, 10V | C12, C53, C73 | 2112754 | MC1206X226M100CT | 0,616 | 5 | 1276-1287-1-ND | 0,265 | 10 | 963-LMK316ABJ226ML-T | 0,155 | 10 | 172-1532 | LMK316ABJ226KL | 0,095 | 50 | CL31A226MOCLNNC | 0,083 | 100 |  | 3 | TME | 0,083 € | 3 | 0,250
4 | 7 | 10n | 0805 | C14, C18, C22, C32, C33, C64, C84 | 2896555 | VJ0805Y103JXXPW1BC | 0,065 | 10 | 490-7194-1-ND | 0,017 | 10 | 710-885012207122 | 0,036 | 10 | 464-6672 | 08055C103KAT2A | 0,026 | 50 | CC0805KRX7R9103 | 0,027 | 100 |  | 7 | Digikey | 0,017 € | 7 | 0,119
5 | 1 | 33p | C0G, 0603 | C15 | 1759197 | MC0805N330J500CT | 0,042 | 10 | 1276-1105-1-ND | 0,048 | 10 | C0805C330K5GACTU | 0,036 | 10 | 264-4264 | C0805C330J5GACTU | 0,069 | 25 | CL21C330JBANNNC | 0,015 | 100 |  | 1 | TME | 0,015 € | 1 | 0,015
6 | 6 | 10n/200V | 1206 | C2, C3, C54, C61, C74, C81 | 2812560 | 885342207005 | 0,078 | 5 | 311-4491-1-ND | 0,150 | 10 | 603-C1206KRX7RABB103 | 0,129 | 10 | 669-8647 | CC1206KRX7RABB103 | 0,128 | 25 | VJ1206Y103KXCTW1BC | 0,019 | 100 |  | 6 | TME | 0,019 € | 6 | 0,114
7 | 2 | 4p7 | C0G, 0603 | C30, C31 | 2627469 | MC0603N4R7C500CT | 0,329 | 10 | 311-1740-1-ND | 0,054 | 10 | 710-885012006049 | 0,072 | 10 | 298-9315 | C0603C479C5GACTU | 0,024 | 25 | CL10C4R7CB8NNNC | 0,024 | 100 |  | 2 | RS | 0,024 € | 2 | 0,048
8 | 1 | 1n | 0805 | C34 | 2896470 | VJ0805A102JXACW1BC | 0,044 | 10 | 732-7858-1-ND | 0,055 | 10 | 710-885012007040 | 0,052 | 10 | 723-6408 | GRM2195C1H102JA01D | 0,031 | 100 | CL21C102JBCNNNC | 0,026 | 100 |  | 1 | TME | 0,026 € | 1 | 0,026
9 | 5 | 1u | 0805 | C36, C51, C55, C71, C75 | 2896566 | VJ0805Y105KXXTW1BC | 0,084 | 5 | 587-1283-1-ND | 0,090 | 10 | 603-CC805MKX7R7BB105 | 0,062 | 10 | 451-5770 | C0805C105K4RACTU | 0,028 | 25 | CL21B105KOFNNNE | 0,010 | 100 |  | 5 | TME | 0,010 € | 5 | 0,052
10 | 7 | 4n7 | C0G, 0805 | C37, C39, C40, C41, C42, C65, C85 | 1828942 | GRM2165C1H472JA01D | 0,184 | 10 | 732-12255-1-ND | 0,162 | 10 | 810-C2012C0G1H472J-1 | 0,072 | 10 | 741-4529 | C2012C0G1H472J060AA | 0,056 | 100 | GRM2165C1H472JA01D | 0,021 | 100 |  | 7 | TME | 0,021 € | 7 | 0,147
11 | 6 | 4u7 | 1206 | C4, C5, C13, C27, C47, C68 | 1907356 | C3216X7R1E475K160AC | 0,240 | 5 | 1276-2970-1-ND | 0,199 | 10 | 963-EMK316B7475ML-T | 0,129 | 10 | 691-1221 | C1206C475K3RACTU | 0,232 | 25 | GCM31CR71E475KA55L | 0,381 | 10 |  | 6 | Mouser | 0,129 € | 6 | 0,774
12 | 2 | EEEFK1H470 | Ø8mm, low ESR | C44, C66 | 9695931 | EEEFK1H470P | 0,419 | 1 | PCE3815CT-ND | 0,590 | 1 | 667-EEE-FK1H470P | 0,524 | 1 | 537-0590 | EEEFK1H470P | 0,510 | 5 | EEEFK1H470P | 0,183 | 5 |  | 2 | TME | 0,183 € | 2 | 0,366
13 | 2 | 100p | C0G, 0805 | C46, C67 | 2896861 | C0805C101JAGACTU | 0,023 | 10 | 399-15000-1-ND | 0,019 | 10 | 80-C0805C101K5G | 0,032 | 10 | 461-3997 | CC0805JRNP09BN101 | 0,030 | 50 | CL21C101JBANNNC | 0,026 | 100 |  | 2 | Digikey | 0,019 € | 2 | 0,038
14 | 4 | 10u | 1210, 50V | C48, C50, C69, C70 | 2672214 | GRT31CR61H106KE01L | 0,684 | 5 | 1276-6736-1-ND | 0,184 | 10 | 810-C3216X7R1HK160AC | 0,597 | 10 | 103-4163 | UMK316BBJ106KL-T | 0,236 | 20 | CL31A106KBHNNNE | 0,546 | 10 |  | 4 | Digikey | 0,184 € | 4 | 0,736
15 | 2 | 220n | 0805 | C52, C72 | 2320828 | MC0805B224J250CT | 0,087 | 5 | 1276-6477-1-ND | 0,520 | 10 | 963-EMK212B7224KG-T | 0,059 | 10 | 103-4126 | UMK212B7224KG-T | 0,039 | 50 | CL21B224KAFNNNE | 0,022 | 100 |  | 2 | TME | 0,022 € | 2 | 0,044
16 | 2 | 680p | 0805 | C56, C76 | 2524913 | 0805B681K500CT | 0,049 | 10 | 1276-2538-1-ND | 0,049 | 10 | 710-885012207085 | 0,036 | 10 | - |  |  |  | CL21C681JBCNNNC | 0,048 | 100 |  | 2 | Mouser | 0,036 € | 2 | 0,072
17 | 4 | 22u | 1210, 25V | C57, C58, C77, C78 | 2320935 | MC1210X226K250CT | 1,490 | 1 | 1276-3373-1-ND | 0,369 | 10 | 603-CC121KKX7R8BB226 | 0,777 | 10 | 766-1182 | CL32A226KAJNNNE | 0,343 | 10 | CL32A226KAJNNNE | 0,158 | 10 |  | 4 | TME | 0,158 € | 4 | 0,632
18 | 2 | EEEFK1V470P | Ø8mm, low ESR | C59, C79 | 9695850 | EEEFK1V470P | 0,368 | 1 | PCE3842CT-ND | 0,460 | 1 | 667-EEE-FK1V470P | 0,445 | 1 | 537-0657 | EEEFK1V470P | 0,422 | 1 | EEEFK1V470P | 0,130 | 5 |  | 2 | TME | 0,130 € | 2 | 0,260
19 | 3 | 2u2 | 1206, 50V | C6, C9, C20 | 2991428 | C1206C225K5RECTU | 0,181 | 5 | 1276-2723-1-ND | 0,132 | 10 | 80-C1206C225M5RECLR | 0,106 | 10 | 184-3509 | UMK316B7225KLHT | 0,151 | 10 | CL31B225KBHNNNE | 0,029 | 50 |  | 3 | TME | 0,029 € | 3 | 0,086
20 | 2 | EEEFK1J101P | Ø10mm, low ESR | C60, C80 | 9696040 | EEEFK1J101P | 1,020 | 1 | PCE3819CT-ND | 0,780 | 1 | 667-EEE-FK1J101P | 0,690 | 1 | 708-3623 | EEEFK1J101P | 0,676 | 5 | EEEFK1J101P | 0,321 | 5 |  | 2 | TME | 0,321 € | 2 | 0,642
21 | 2 | 470p | 0805 | C62, C82 | 1759217 | MC0805N471J500CT | 0,061 | 10 | 732-7837-1-ND | 0,059 | 10 | 710-885012007038 | 0,056 | 10 | 378-700 | 0805CG471J9BB | 0,040 | 25 | CC0805JRNPO9BN471 | 0,024 | 100 |  | 2 | TME | 0,024 € | 2 | 0,048
22 | 2 | 33n | 0805 | C63, C83 | 2627479 | MC0805B333K250CT | 0,046 | 10 | 1276-1796-1-ND | 0,057 | 10 | 710-885012207069 | 0,036 | 10 | 135-6639 | 08051C333KAT2A | 0,021 | 100 | CC0805KRX7R9333 | 0,016 | 100 |  | 2 | TME | 0,016 € | 2 | 0,032
23 | 17 | 100n | 0603 | C7, C8, C10, C16, C17, C19, C23, C24, C25, C26, C28, C29, C35, C38, C43, C45, C49 | 2522597 | C0603C104K4RAC7081 | 0,011 | 10 | 490-4774-1-ND | 0,029 | 100 | 80-C0603C104M4R | 0,007 | 100 | 393-6952 | VJ0603Y104KXJAT | 0,069 | 25 | CL10B104KA8NNNC | 0,098 | 100 |  | 17 | Mouser | 0,007 € | 17 | 0,119
24 | 8 | SKL16 | SOD-123 | D1, D2, D3, D4, D5, D6, D7, D8 | 2673070 | RB160MM-60TR | 0,282 | 5 | RB160MM-60CT-ND | 0,264 | 10 | 755-RB160MM-60TR | 0,233 | 10 | 124-6774 | RB160MM-60TR | 0,230 | 40 | SKL16-DIO | 0,105 | 5 |  | 8 | TME | 0,105 € | 8 | 0,840
25 | 1 | BLM18AG102SH1D | 0603 | FB1 | 1515671 | BLM18AG102SN1D | 0,053 | 10 | 490-7809-1-ND | 0,081 | 10 | 81-BLM18AG102SH1D | 0,063 | 10 | 839-0803 | BLM18AG102SH1D | 0,043 | 100 | BLM18AG102SH1D | 0,016 | 50 |  | 1 | TME | 0,016 € | 1 | 0,016
26 | 1 | Si8662AB-B-IS1 | SOIC-16 | IC1 | 2423351 | SI8662AB-B-IS1 | 1,850 | 1 | SI8662AB-B-IS1-ND | 1,920 | 1 | 634-SI8662AB-B-IS1 | 1,760 | 1 | 823-2062 | Si8662AB-B-IS1 | 1,870 | 5 | - |  |  |  | 1 | Mouser | 1,760 € | 1 | 1,760
27 | 2 | LT3763EFE#PBF | TSSOP-28 | IC10, IC12 | - |  |  |  | LT3763EFE#PBF-ND | 4,950 | 1 | 584-LT3763EFE#PBF | 4,830 | 1 | - |  |  |  |  |  |  |  | 2 | Mouser | 4,830 € | 2 | 9,660
28 | 1 | MC33274ADR2G | SOIC-14 | IC11 | 2531387 | MC33274ADR2G | 1,010 | 1 | MC33274ADR2GOSCT-ND | 1,190 | 1 | 863-MC33274ADR2G | 1,020 | 1 | 773-7787 | MC33274ADR2G | 1,010 | 2 | MC33274ADR2G | 0,740 | 1 |  | 1 | TME | 0,740 € | 1 | 0,740
29 | 1 | TPS54060DGQ | MSOP-10 | IC2 | 1710820 | TPS54060DGQ . | 3,030 | 1 | 296-37148-1-ND | 2,630 | 1 | 595-TPS54060DGQR | 2,490 | 1 | 698-9079 | TPS54060DGQ | 2,680 | 1 | - |  |  |  | 1 | Mouser | 2,490 € | 1 | 2,490
30 | 1 | Si8641AB-B-IS1 | SOIC-16 | IC3 | 2423288 | Si8641AB-B-IS1 | 1,460 | 1 | SI8641AB-B-IS1-ND | 1,530 | 1 | 634-SI8641AB-B-IS1 | 1,410 | 1 | 823-2000 | Si8641AB-B-IS1 | 1,496 | 5 | - |  |  |  | 1 | Mouser | 1,410 € | 1 | 1,410
31 | 1 | M24C32-WMN6P | SOIC-8 | IC4 | 1224413 | M24C32-WMN6P | 0,212 | 5 | - |  |  | 511-M24C32-WMN6P | 0,210 | 1 | 686-2453 | M24C32-WMN6P | 0,180 | 25 | M24C32-WMN6P | 0,165 | 3 |  | 1 | TME | 0,165 € | 1 | 0,165
32 | 1 | LP2985-33DBVR | SOT-23-5 | IC5 | 1053660 | LP2985A-33DBVTE4 . | 0,610 | 1 | 296-18476-1-ND | 0,540 | 1 | 595-LP2985-33DBVR | 0,507 | 1 | 660-6733 | LP2985-33DBVT | 0,737 | 1 | LP2985-33DBVR | 0,362 | 1 |  | 1 | TME | 0,362 € | 1 | 0,362
33 | 1 | 74HC2G04GW,125 |  | IC6 | 2777732 | 74HC2G04GW,125 | 0,283 | 5 | 1727-6045-1-ND | 0,274 | 10 | 771-HC2G04GW125 | 0,248 | 10 | 153-2919 | 74HC2G04GW,125 | 0,235 | 50 | 74HC2G04GW.125 | 0,138 | 5 |  | 1 | TME | 0,138 € | 1 | 0,138
34 | 1 | STM32F373C8T6 | LQFP-48 | IC7 | 2333274 | STM32F373C8T6 | 4,420 | 1 | 497-13306-ND | 3,940 | 1 | 511-STM32F373C8T6 | 3,840 | 1 | 795-9164 | STM32F373C8T6 | 2,060 | 1 | - |  |  |  | 1 | RS | 2,060 € | 1 | 2,060
35 | 1 | TL431BIDBZR | SOT-23 | IC8 | 2095470 | TL431BCDBZR | 0,310 | 5 | 296-18866-1-ND | 0,305 | 10 | 771-TL431BIDBZR215 | 0,342 | 10 | 797-4826 | TL431BIDBZR,215 | 0,259 | 2 | TL431BIDBZR | 0,237 | 3 |  | 1 | TME | 0,237 € | 1 | 0,237
36 | 1 | MC33272ADR2G | SOIC-8 | IC9 | 2531389 | MC33272ADR2G | 0,854 | 1 | MC33272ADR2GOSCT-ND | 0,910 | 1 | 863-MC33272ADR2G | 0,865 | 1 | 773-7778 | MC33272ADR2G | 0,865 | 1 | MC33272ADR2G | 0,570 | 1 |  | 1 | TME | 0,570 € | 1 | 0,570
37 | 1 | 4907 | THT, PCB terminal; 4.8mm | J1 | - |  |  |  | 36-4907-ND | 0,260 | 1 | 534-4907 | 0,257 | 1 | - |  |  |  | 61-1537-11/0031 | 0,049 | 10 | 1 |  | TME | 0,049 € | 1 | 0,049
38 | 2 | 571-0500 | THT, Ø4 mm terminal; red | J2, J4 | 1101127 | 571-0500-01 | 1,720 | 5 | - |  |  | 164-6219 | 2,040 | 1 | 103-6511 | 571-0500 | 1,216 | 5 | 571-0500 | 0,620 | 3 | 2 |  | TME | 0,620 € | 2 | 1,240
39 | 2 | 571-0100 | THT, Ø4 mm terminal; black | J3, J5 | 1101128 | 571-0100-01 | 1,740 | 5 | - |  |  | 164-6218 | 1,840 | 1 | 103-6527 | 571-0100 | 1,334 | 5 | 571-0100 | 0,620 | 3 | 2 |  | TME | 0,620 € | 2 | 1,240
40 | 1 | RN112-4-02-0M7 | THT, Current-compensated Choke | L1 | - |  |  |  | 817-2100-ND | 1,560 | 1 | 631-RN112-4-02-0M7 | 1,400 | 1 | - |  |  |  | - |  |  | 1 |  | Mouser | 1,400 € | 1 | 1,400
41 | 2 | 125CDMCCDS-330MC | Power inductor | L2, L4 | 2211631 | 7443551331 | 3,930 | 1 | 308-2568-1-ND | 1,510 | 1 | 851-125CDMCCDS330MC | 1,590 | 1 | - |  |  |  | - |  |  |  | 2 | Digikey | 1,510 € | 2 | 3,020
42 | 2 | HPI0630-3R3 | Power inductor | L3, L5 | 1741325 | IHLP2020CZER3R3M11 | 1,940 | 5 | 445-180834-1-ND | 0,510 | 1 | 810-VLS6045AF-3R3N | 0,510 | 1 | - |  |  |  | HPI0630-3R3 | 0,335 | 1 |  | 2 | TME | 0,335 € | 2 | 0,670
43 | 2 | WP42WUM/EGW | THT, dual (green/red) 3 mm LED | LED1, LED2 | - |  |  |  | 754-1718-ND | 0,930 | 1 | 604-WP42WUM/EGW | 0,926 | 1 | - |  |  |  | L-42WUM/1EGWT | 0,501 | 1 | 2 |  | TME | 0,501 € | 2 | 1,002
44 | 2 | NTCS0805E3103JMT | NTC 0805 | NTC1, NTC2 | 2103177 | NTCS0805E3103JMT | 0,399 | 10 | BC2292CT-ND | 0,490 | 1 | 594-2381-615-53103 | 0,353 | 10 | 179-3950 | NTCS0805E3103JMT | 0,250 | 250 | NTCS0805E3103JMT | 0,113 | 15 |  | 2 | TME | 0,113 € | 2 | 0,226
45 | 2 | BSP716NH6327XTSA1 | SOT-223 | Q1, Q7 | 2803380 | BSP716NH6327XTSA1 | 0,378 | 5 | BSP716NH6327XTSA1CT-ND | 0,372 | 10 | 726-BSP716NH6327XTSA | 0,333 | 10 | - |  |  |  | BSP716NH6327XTSA1 | 0,201 | 3 |  | 2 | TME | 0,201 € | 2 | 0,402
46 | 6 | NTD5867NLT4G | DPAK | Q2, Q3, Q4, Q8, Q9, Q10 | 1879964 | NTD5867NLT4G | 0,493 | 10 | NTD5867NLT4GOSCT-ND | 0,458 | 10 | 863-NTD5867NLT4G | 0,430 | 10 | 719-2901 | NTD5867NLT4G | 0,524 | 5 | NTD5867NLT4G | 0,310 | 3 |  | 6 | TME | 0,310 € | 6 | 1,860
47 | 2 | BSS205NH6327XTSA1 | SOT-23 | Q5, Q11 | 2480648 | BSS205NH6327XTSA1 | 0,257 | 5 | BSS205NH6327XTSA1CT-ND | 0,274 | 10 | BSS205NH6327XTSA1 | 0,236 | 10 | 892-2374 | BSS205NH6327XTSA1 | 0,108 | 100 | BSS205NH6327XTSA1 | 0,097 | 10 |  | 2 | TME | 0,097 € | 2 | 0,194
48 | 2 | BSS84P | SOT-23 | Q6, Q12 | 1056526 | BSS84PH6327XTSA2 | 0,224 | 5 | BSS84PH6433XTMA1CT-ND | 0,314 | 10 | 726-BSS84PH6327XTSA2 | 0,196 | 10 | - |  |  |  | BSS84P | 0,060 | 10 |  | 2 | TME | 0,060 € | 2 | 0,120
49 | 11 | 10K | 0805 | R10, R11, R12, R13, R14, R15, R16, R17, R18, R19, R20 | 9237755 | RC0805FR-0710KL | 0,022 | 10 | 311-10.0KCRCT-ND | 0,039 | 10 | 603-RC0805FR-0710KL | 0,014 | 10 | 125-1189 | CRG0805F10K | 0,002 | 100 | 0805S8F1002T5E | 0,014 | 100 |  | 11 | RS | 0,002 € | 11 | 0,022
50 | 9 | 10R | 0805 | R2, R4, R5, R28, R39, R42, R51, R62, R65 | 2447556 | MCWR08X10R0FTL | 0,007 | 10 | 311-10.0CRCT-ND | 0,064 | 10 | 71-CRCW080510R0FKEAC | 0,047 | 10 | 223-0152 | CRG0805F10R | 0,019 | 50 | 0805S8F100JT5E | 0,015 | 100 |  | 9 | Farnell | 0,007 € | 9 | 0,059
51 | 4 | 3K3 | 0805 | R21, R22, R46, R69 | 2447651 | MCWR08X3301FTL | 0,010 | 10 | A129755CT-ND | 0,045 | 10 |  |  |  | 223-0499 | CRG0805F3K3 | 0,027 | 50 | 805S8F3301T5E | 0,015 | 100 |  | 4 | Farnell | 0,010 € | 4 | 0,039
52 | 3 | 120R | 0805 | R23, R48, R71 | 2447561 | MCWR08X1200FTL | 0,009 | 10 | RMCF0805FT120RCT-ND | 0,020 | 10 | 71-CRCW0805120RFKEAC | 0,037 | 10 | 223-0304 | CRG0805F120R | 0,035 | 50 | 0805S8F1200T5E | 0,022 | 100 |  | 3 | Farnell | 0,009 € | 3 | 0,028
53 | 5 | 47K | 0805 | R3, R41, R47, R64, R70 | 2447664 | MCWR08X4702FTL | 0,009 | 10 | RHM47KKCT-ND | 0,036 | 10 | 603-RC0805FR-0747KL | 0,014 | 10 | 679-1434 | CRCW080547K0FKEA | 0,036 | 50 | RC0805FR-0747K | 0,022 | 100 |  | 5 | Farnell | 0,009 € | 5 | 0,047
54 | 4 | 20K | 0805 | R30, R32, R53, R55 | 2447603 | MCWR08X2002FTL | 0,009 | 10 | A126349CT-ND | 0,047 | 10 | RCG080520K0FKEA | 0,034 | 50 | 679-1077 | CRCW080520K0FKEA | 0,038 | 50 | RC0805FR-0720K | 0,035 | 100 |  | 4 | Farnell | 0,009 € | 4 | 0,038
55 | 4 | 12K | 0805 | R31, R33, R54, R56 | 2447563 | MCWR08X1202FTL | 0,010 | 10 | A126337CT-ND | 0,047 | 10 | 71-CRCW080512K0FKEA | 0,058 | 10 | 223-0578 | CRG0805F12K | 0,020 | 50 | SMD0805-12K-1% | 0,014 | 100 |  | 4 | Farnell | 0,010 € | 4 | 0,040
56 | 2 | R010/2W | 2512 | R34, R57 | 2709394 | CRF2512-FZ-R010ELF | 0,779 | 10 | MCS3264R010FERCT | 0,568 | 10 | 754-KRL3264ECR010FT1 | 0,590 | 10 | 693-4381 | CRA2512-FZ-R010ELF | 0,496 | 10 | LRP12FTWRR010 | 0,151 | 10 |  | 2 | TME | 0,151 € | 2 | 0,302
57 | 2 | 22R/0.5W | 1206 | R35, R58 | 2331841 | CRGH1206J22R | 0,035 | 10 | 118-CRM1206-FX-22R0ELFCT-ND | 0,106 | 10 | 603-RC1206JR-7W22RL | 0,103 | 10 | - |  |  |  | HP06W2J0220T5E | 0,042 | 50 |  | 2 | Farnell | 0,035 € | 2 | 0,070
58 | 2 | 36K | 0805 | R37, R60 | 2447643 | MCWR08X3602FTL | 0,007 | 10 | 311-36.0KCRCT-ND | 0,037 | 10 | 603-RT0805FRE0736KL | 0,050 | 10 | 679-1314 | CRCW080536K0FKEA | 0,004 | 50 | 0805S8F3602T5E | 0,015 | 100 |  | 2 | RS | 0,004 € | 2 | 0,008
59 | 2 | 68K | 0805 | R38, R61 | 2447706 | MCWR08X6802FTL | 0,007 | 10 | A126382CT-ND | 0,045 | 10 | 603-RT0805FRE0768KL | 0,058 | 10 | 679-1620 | CRCW080568K0FKEA | 0,038 | 50 | 0805S8F6802T5E | 0,015 | 100 |  | 2 | Farnell | 0,007 € | 2 | 0,014
60 | 2 | 150K | 0805 | R40, R63 | 2447573 | MCWR08X1503FTL | 0,008 | 10 | A126340CT-ND | 0,045 | 10 | 279-CRGCQ0805F150K | 0,038 | 10 | 223-0714 | CRG0805F150K | 0,023 | 50 | 0805S8J0154T5E | 0,013 | 100 |  | 2 | Farnell | 0,008 € | 2 | 0,016
61 | 2 | 3K6 | 0805 | R44, R67 | 2447652 | MCWR08X3601FTL | 0,010 | 10 | RMCF0805FT3K60CT-ND | 0,010 | 100 | 603-RT0805FRE073K6L | 0,017 | 100 | 865-4425 | ERJU06F3601V | 0,039 | 50 | 0805S8F3601T5E | 0,007 | 100 |  | 2 | TME | 0,007 € | 2 | 0,014
62 | 2 | 7K5 | 0805 | R45, R68 | 2447722 | MCWR08X7501FTL | 0,007 | 10 | A126387CT-ND | 0,045 | 10 | 652-CR0805FX-7501ELF | 0,032 | 10 | 679-1686 | CRCW08057K50FKEA | 0,038 | 50 | 0805S8F7501T5E | 0,015 | 100 |  | 2 | Farnell | 0,007 € | 2 | 0,014
63 | 2 | 11K8 | 0805 | R49, R72 | 2138981 | CRCW080511K8FKEA. | 0,040 | 10 | 311-11.8KCRCT-ND | 0,037 | 10 | 603-RC0805FR-0711K8L | 0,010 | 100 | 679-0847 | CRCW080511K8FKEA | 0,036 | 50 | 0805S8F1182T5E | 0,014 | 100 |  | 2 | Mouser | 0,010 € | 2 | 0,020
64 | 2 | 15K | 0805 | R50, R73 | 1099808 | WCR0805-15KFI | 0,019 | 10 | A126341CT-ND | 0,041 | 10 | 71-CRCW080515K0FKEBC | 0,013 | 10 | 223-0584 | CRG0805F15K | 0,023 | 50 | SMD0805-15K | 0,013 | 100 |  | 2 | Mouser | 0,013 € | 2 | 0,026
65 | 7 | 2K2 | 0805 | R6, R24, R25, R26, R27, R36, R59 | 9237534 | RC0805FR-072K2L | 0,037 | 10 | 311-2.20KCRCT-ND | 0,039 | 10 | 603-RC0805FR-072K2L | 0,026 | 10 | 679-1207 | CRCW08052K20FKEA | 0,039 | 50 | 0805S8F2201T5E | 0,022 | 100 |  | 7 | TME | 0,022 € | 7 | 0,156
66 | 6 | 86K6 | 0805 | R7, R9, R29, R43, R52, R66 | 2303750RL | ERJ6ENF8662V | 0,058 | 10 | 311-86.6KCRCT-ND | 0,036 | 10 | 603-RT0805FRE0786K6L | 0,056 | 10 | - |  |  |  | CRCW080586K6FKTABC | 0,025 | 100 |  | 6 | TME | 0,025 € | 6 | 0,150
67 | 2 | 3K3, 0.25W | 1206 | R74, R75 | 2447514 | MCWR12X3301FTL | 0,014 | 10 | RC1206FR-073K3L | 0,090 | 10 | 71-CRCW12063K30FKEAC | 0,069 | 10 | 223-2338 | CRG1206F3K3 | 0,017 | 10 | 1206S4J0332T5E | 0,012 | 100 |  | 2 | TME | 0,012 € | 2 | 0,024
68 | 1 | 330K | 0805 | R8 | 2447637 | MCWR08X3303FTL | 0,010 | 10 | A126361CT-ND | 0,046 | 10 | 652-CR0805FX-3303ELF | 0,013 | 10 | 679-1272 | CRCW0805330KFKEA | 0,038 | 50 | SMD0805-330K-1% | 0,015 | 100 |  | 1 | Farnell | 0,010 € | 1 | 0,010
69 | 1 | DR1206-33R-4/8 | 1206 resistor array | RN1 | 1770128 | CAY16-330J4LF | 0,069 | 10 | CAY16-330J4LFCT-ND | 0,090 | 1 | 652-CAY16-330J4LF | 0,085 | 1 | 522-5670 | CAY16-330J4LF | 0,004 | 50 | DR1206-33R-4/8 | 0,009 | 100 |  | 1 | RS | 0,004 € | 1 | 0,004
70 | 1 | SRF0703-821M | 0703 | TR1 | 1852832 | SRF0703-821M | 0,827 | 1 | SRF0703-821MCT-ND | 0,900 | 1 | 652-SRF0703-821M | 0,681 | 1 | - |  |  |  | - |  |  |  | 1 | Mouser | 0,681 € | 1 | 0,681
71 | 1 | 39-30-1020 | THT, Minifit Jr. 2-pin, right angle | X1 | 9732080 | 39-28-1023 | 0,367 | 1 | WM3800-ND | 0,530 | 1 | 538-39-28-1023 | 0,530 | 1 | 484-1883 | 39-28-102 | 0,354 | 5 | MX-39-30-1020 | 0,339 | 5 | 1 |  | TME | 0,339 € | 1 | 0,339
72 | 1 | 77317-104-28LF | THT, 28-pin 0.1" header right angled | X2 | - |  |  |  | S2111EC-14-ND | 1,030 | 1 | 649-77317-104-28LF | 1,540 | 1 | - |  |  |  | - |  |  | 1 |  | Digikey | 1,030 € | 1 | 1,030
73 | 1 | DS1024-2*5R0 | THT, 10-pin 0.1" receptacle right angled | X4 | 1841243 | 613010243121 | 0,910 | 1 | S9202-ND | 0,720 | 1 | 710-613010243121 | 0,950 | 1 | 826-7194 | 613010243121 | 0,950 | 1 | ZL263-10DG | 0,301 | 2 | 1 |  | TME | 0,301 € | 1 | 0,301
74 | 1 | LF XTAL026392 | 16 MHz XTAL; 7.5x5.1x1.4mm | Y1 | 1276696 | LFXTAL026392 | 1,250 | 1 | 1923-1009-ND | 0,850 | 1 | 449-LFXTAL026392BULK | 0,972 | 1 | 148-4357 | LFXTAL026392 | 0,960 | 10 | 16.00M-12SM | 0,950 | 1 |  | 1 | Digikey | 0,850 € | 1 | 0,850
75 | 3 | SMAJ51A | SMA | ZD1, ZD3, ZD5 | 2677667 | SMAJ51A | 0,144 | 5 | SMAJ51ALFCT-ND | 0,370 | 1 | 652-SMAJ51A | 0,463 | 1 | 171-4238 | SMAJ51A | 0,320 | 25 | SMAJ51A-LF | 0,201 | 3 |  | 3 | Farnell | 0,144 € | 3 | 0,432
76 | 2 | MM3Z9V1T1G | SOD-323 | ZD2, ZD4 | 2463517 | MM3Z9V1T1G | 0,124 | 5 | MM3Z9V1T1GOSCT-ND | 0,120 | 1 | 863-MM3Z9V1T1G | 0,108 | 10 | 802-4653 | MM3Z9V1T1G | 0,039 | 200 | MM3Z9V1T1G | 0,020 | 25 |  | 2 | TME | 0,020 € | 2 | 0,041
 |  |  |  |  |  |  |  |  |  |  |  |  |  |  |  |  |  |  |  |  |  | 11 | 205 |  |  |  | 41,52 €
 |  | Not installed
 | 1 | N.C. | 0805 | C21 |  |  |  |  |  |  |  |  |  |  |  |  |  |  |  |  |  |  | 1 | Farnell | 0,000 € | 1 | 0,000
 | 1 | N.C. | 2512 | R1 | 2081875 | ASC2512-4K7FT4 | 0,195 | 10 | A130729CT-ND | 0,331 | 10 | 279-CRGP2512F4K7 | 0,180 | 10 | 224-0424 | 35204K7JT | 1,370 | 10 | CRCW25124K70FKTHBC | 0,113 | 10 |  | 1 | TME | 0,113 € | 1 | 0,113
 | 1 | DR1206-33R-4/8 | 1206 resistor array | RN2 | 1770128 | CAY16-330J4LF | 0,069 | 10 | CAY16-330J4LFCT-ND | 0,090 | 1 | 652-CAY16-330J4LF | 0,085 | 1 | 522-5670 | CAY16-330J4LF | 0,004 | 50 | DR1206-33R-4/8 | 0,009 | 100 |  | 1 | RS | 0,004 € | 1 | 0,004
 | 1 | 22-23-2061 | THT | X3 |  |  |  |  |  |  |  |  |  |  |  |  |  |  |  |  |  | 1 |  | Farnell | 0,000 € | 1 | 0,000
 |  | Custom made components
 | 1 | PCB | 4-layer 145 x 95 mm, 1 oz. Cu thickness (MOQ: 5, incl. S&H) |  |  |  |  |  |  |  |  |  |  |  |  |  |  |  |  |  |  |  |  | JLCPCB | 10,892 € | 1 | 10,892
 |  |  |  |  |  |  |  |  |  |  |  |  |  |  |  |  |  |  |  |  |  |  |  |  |  |  | 10,89 €
 |  |  | All prices are net prices (without VAT)
 |  |  |  |  |  |  |  |  |  |  |  |  |  |  |  |  |  |  |  |  |  |  |  |  |  | Total | 52,42 €
 |  |  | Please note that BOM does not contain ordering number for parts on reels or that which includes re-reeling fee (e.g. Farnell). Take also into account that total cost is higher because min. quantity (MOQ) for many parts is larger then what is needed for single unit.
 |  |  | All resistors are 1% 0805 and all capacitors are X7R 0805 if not otherwise specified.

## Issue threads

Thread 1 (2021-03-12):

Problem with voltage measurement in PWM mode

prasimix, 2021-03-12:
If PWM (dimming) mode is selected, output voltage will be wrongly reported if second channel is not turned on (i.e. its PWM MOSFET is turned on). That could create confusion and OVP probably will not work properly in that case. R45 and R68 probably should be connected to GND instead of Vout-

prasimix, 2021-07-19:
Fixed

Closed 2021-07-19.

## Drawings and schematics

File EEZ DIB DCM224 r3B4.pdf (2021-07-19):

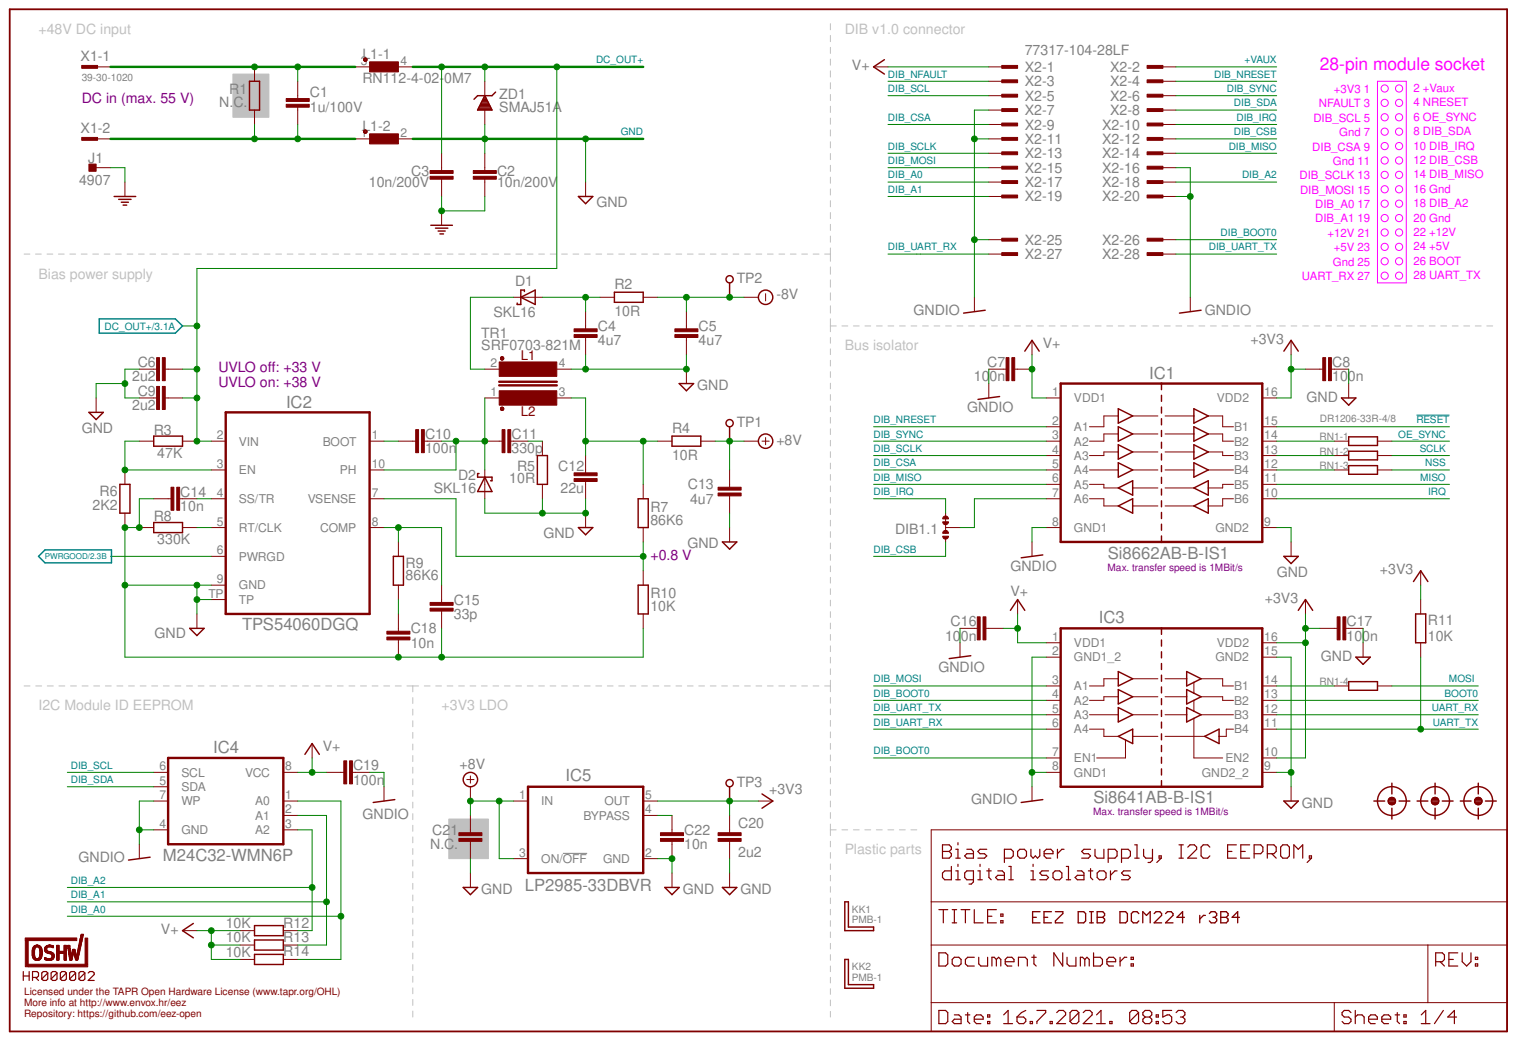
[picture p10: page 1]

Max. transfer speed is 1MBit/s

Licensed under the TAPR Open Hardware License (www.tapr.org/OHL) Repository: https://github.com/eez-open More info at http://www.envox.hr/eez

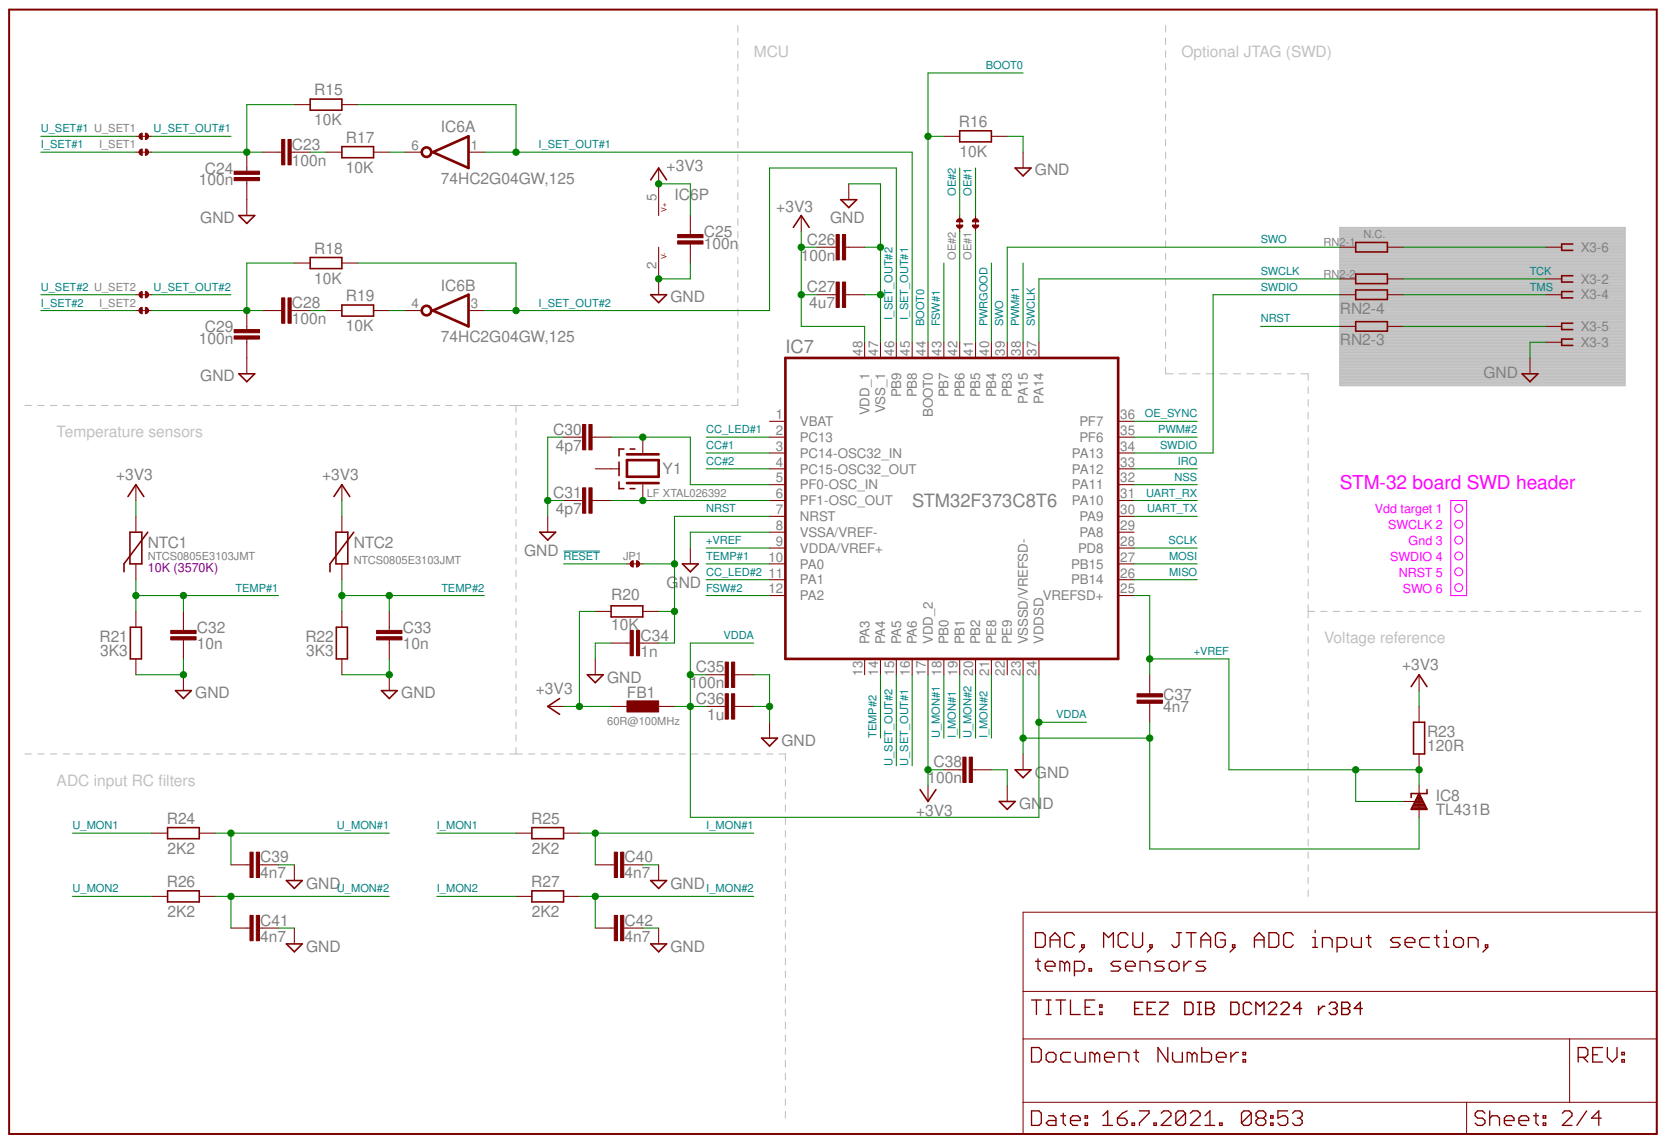
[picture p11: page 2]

NRST | RN2-3 X3-2 X3-3 X3-4 X3-5
SWDIO

SWDIO 4 SWCLK 2 Vdd target 1 STM-32 board SWD header Gnd 3 NRST 5 SWO 6

ADC input RC filters

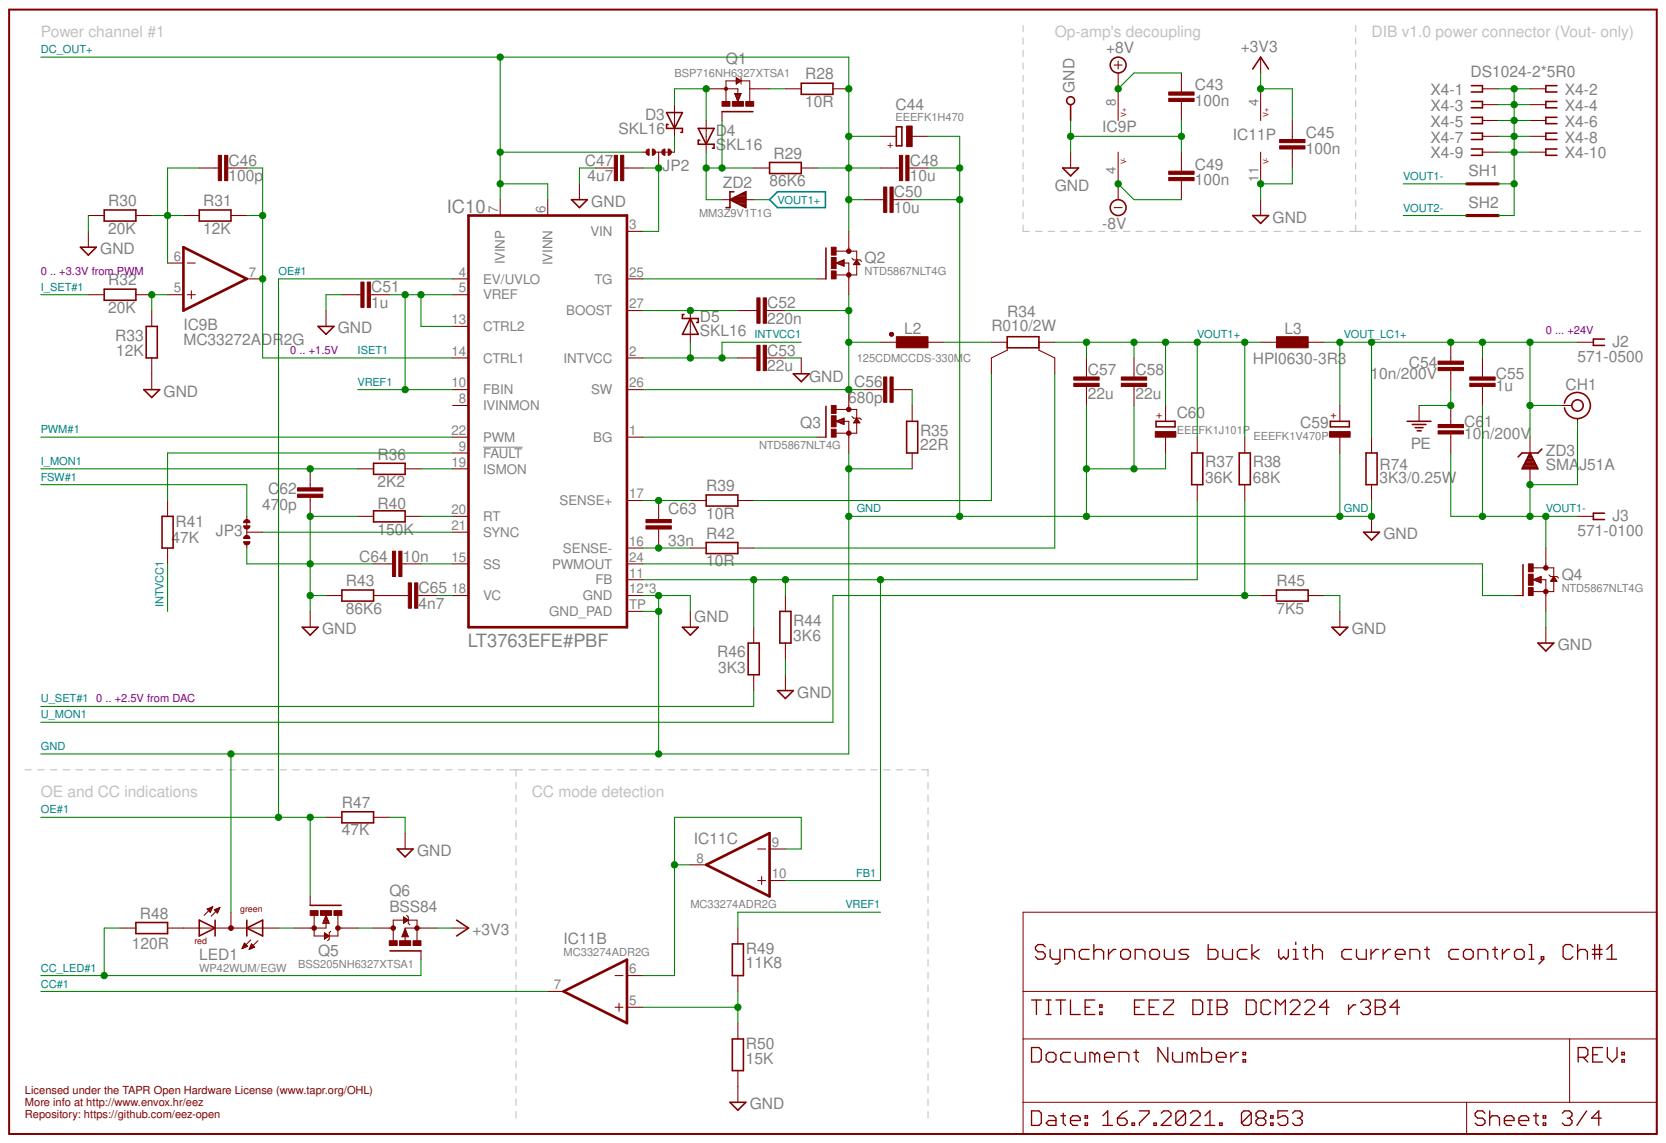
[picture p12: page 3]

11 | R45
12*3

OE and CC indications

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

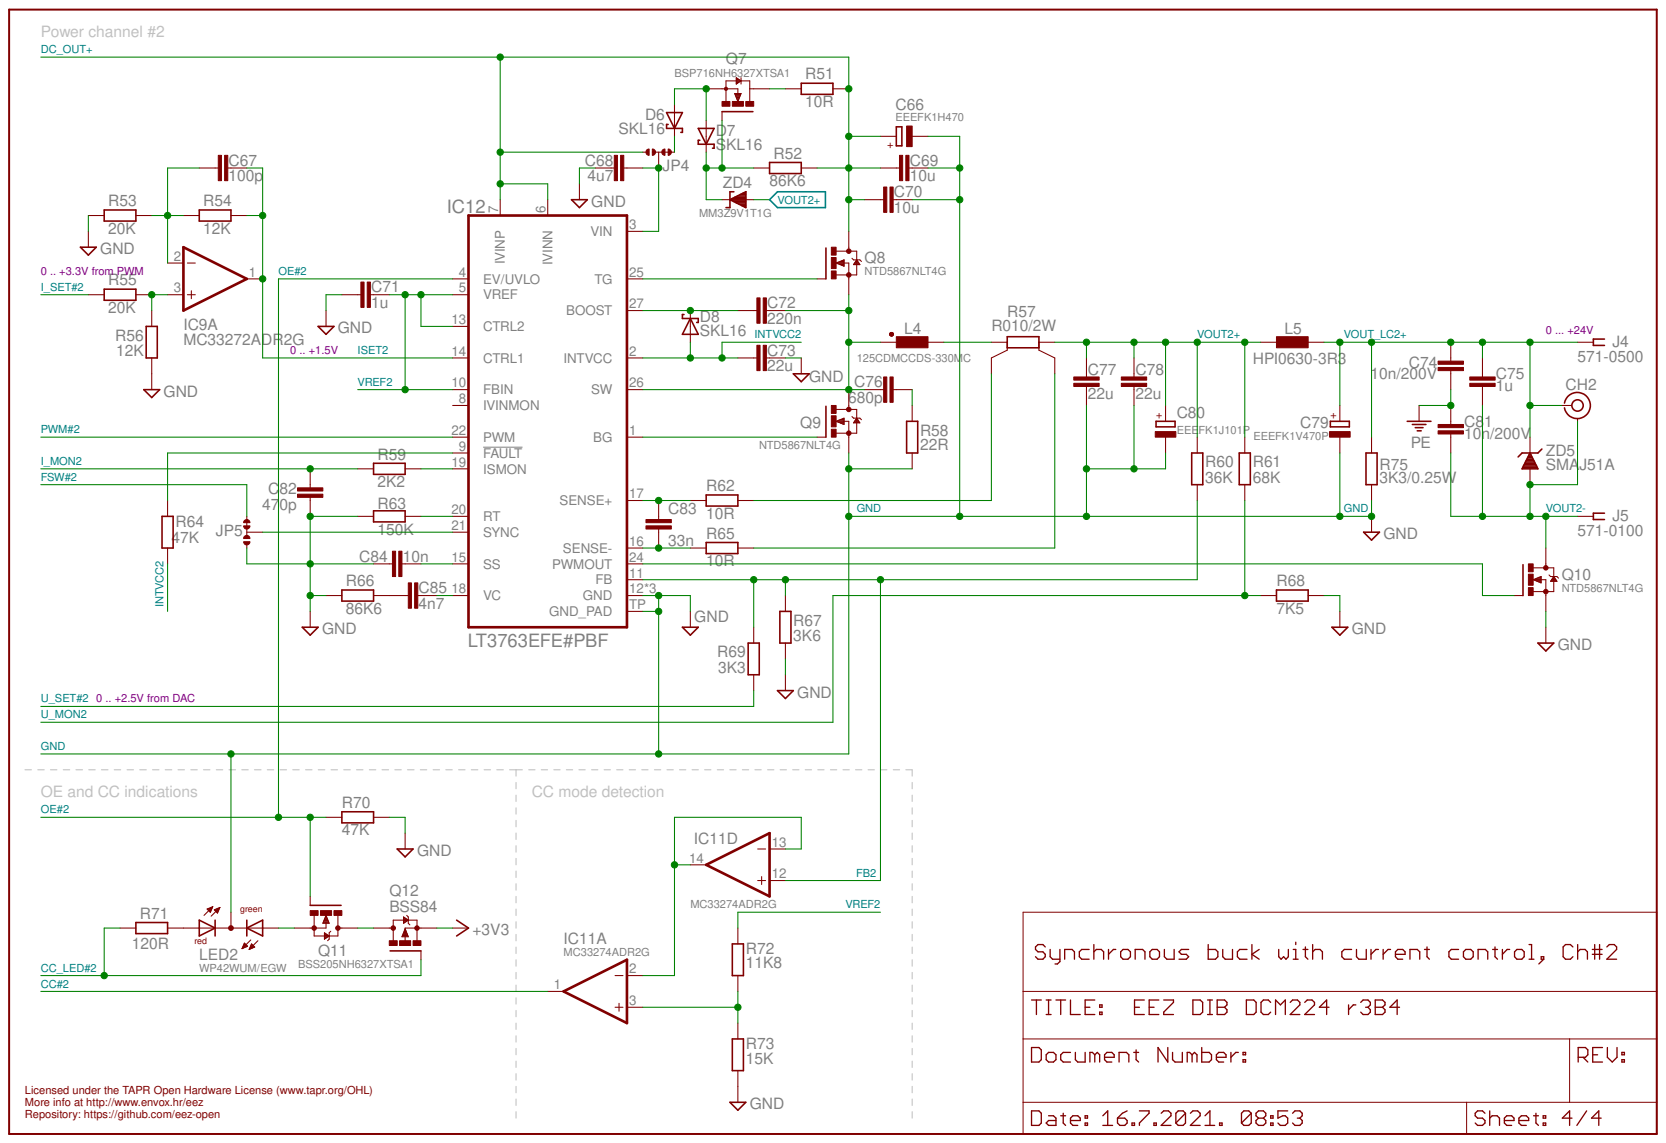
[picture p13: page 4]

11 | R68
12*3

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

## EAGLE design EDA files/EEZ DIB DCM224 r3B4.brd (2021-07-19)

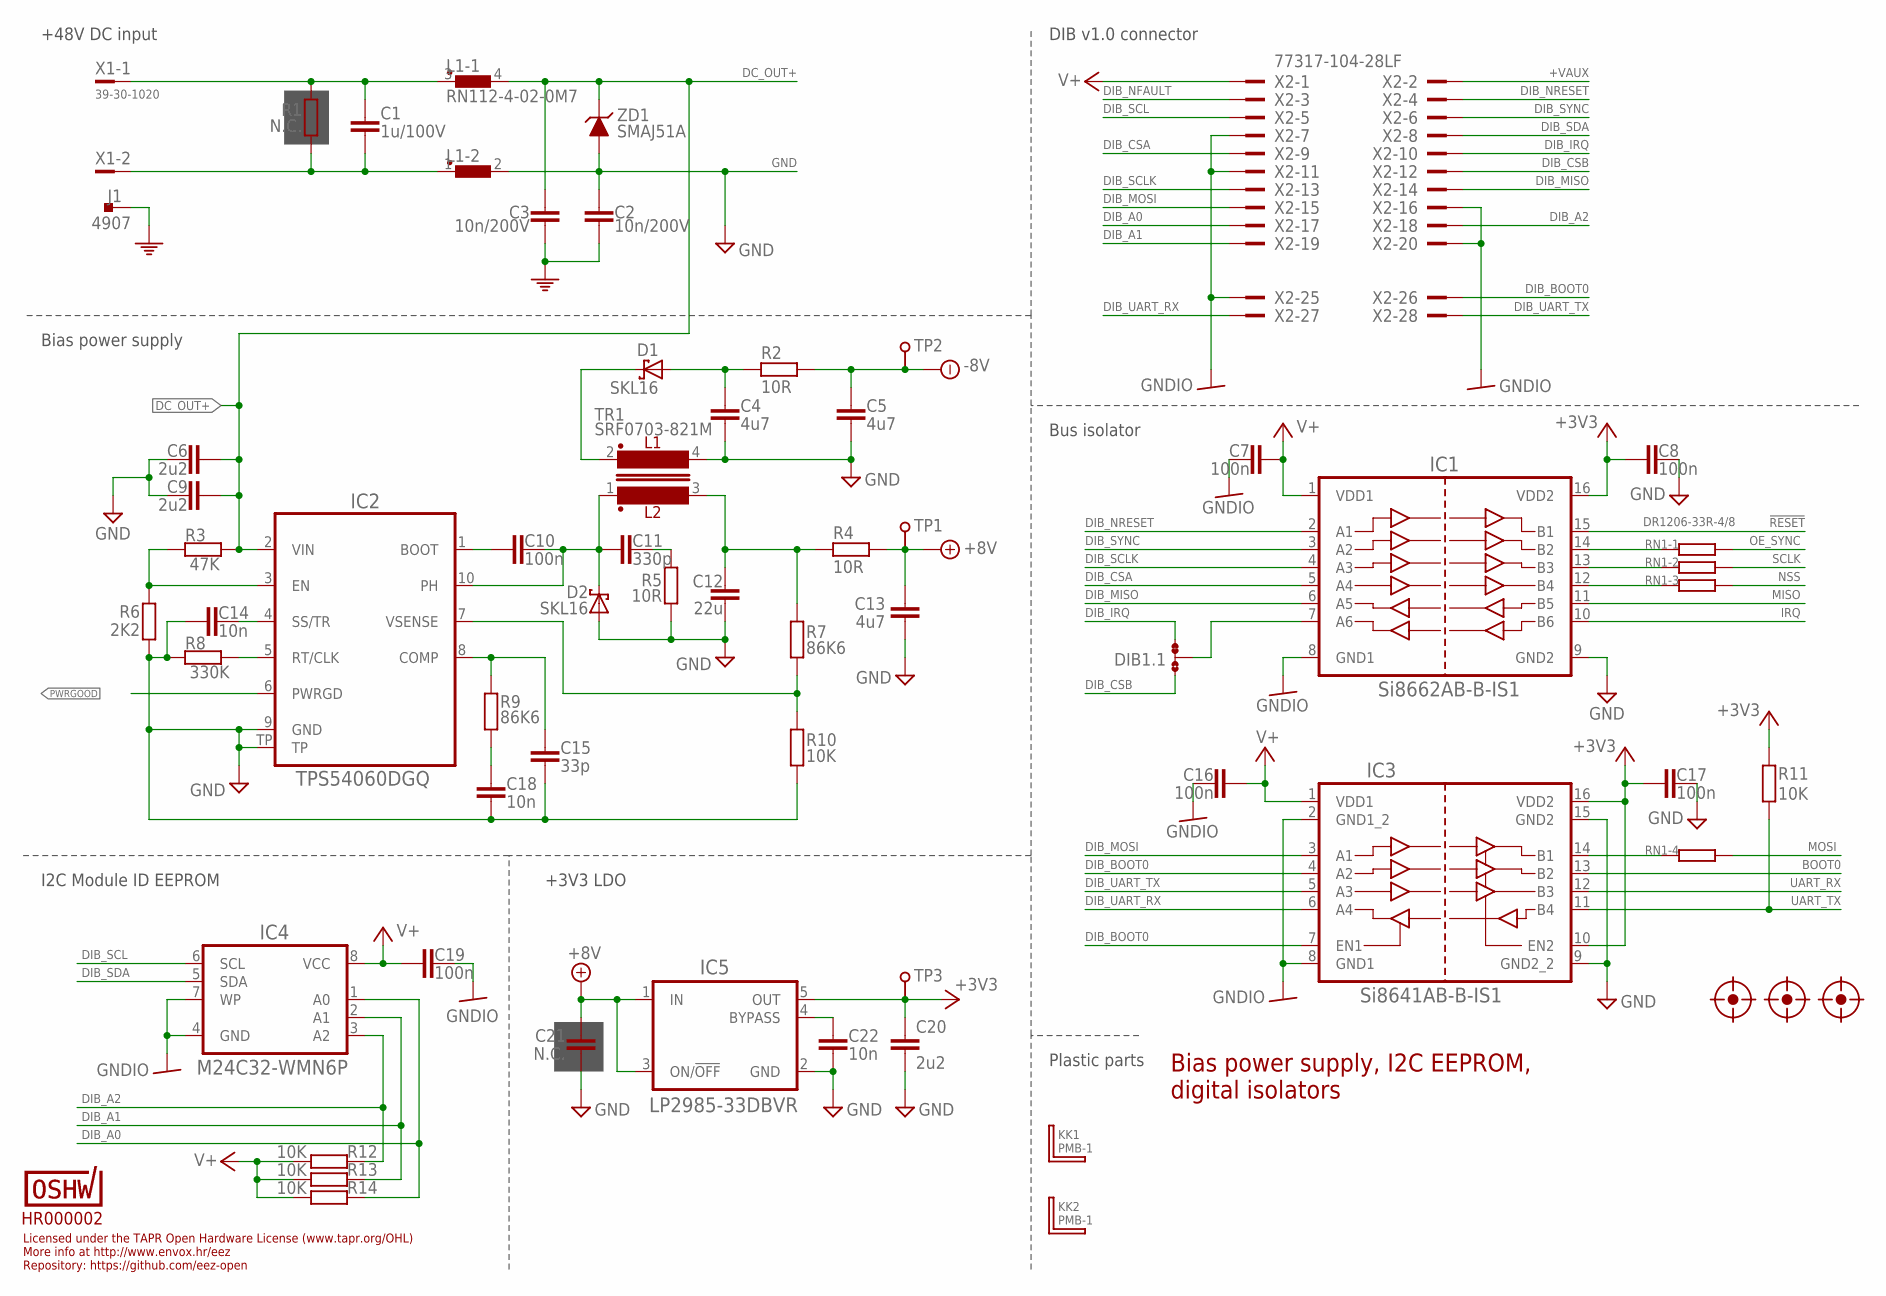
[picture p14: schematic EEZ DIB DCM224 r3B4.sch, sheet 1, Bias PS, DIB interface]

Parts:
C1: 1u/100V; C1206
C2, C3: 10n/200V; C1206
C4, C5, C13: 4u7; C1206
C6, C9, C20: 2u2; C1206
C7, C8, C10, C16, C17, C19: 100n; C0603
C11: 330p; C0805
C12: 22u; C1206
C14, C18, C22: 10n; C0805
C15: 33p; C0603
C21: N.C.; C0805
D1, D2: SKL16; SOD123
DIB1.1: JP3-CUT-0805-ROTATED; JP3-0805-CUT2
FM1, FM2, FM3: FIDUCIAL_2; FIDUCIAL_DUAL
IC1: Si8662AB-B-IS1; SOIC-16
IC2: TPS54060DGQ; SOP50P490X110-11N
IC3: Si8641AB-B-IS1; SOIC-16
IC4: M24C32-WMN6P; SOIC127P600X173-8N
IC5: LP2985-33DBVR; SOT95P270X145-5N
J1: 4907; PCB_TAB-4907
KK1, KK2: PMB-1; PCB-MB
L1: RN112-4-02-0M7; RN112
R1: N.C.; R2512
R2, R4, R5: 10R; R0805
R3: 47K; R0805
R6: 2K2; R0805
R7, R9: 86K6; R0805
R8: 330K; R0805
R10, R11, R12, R13, R14: 10K; R0805
RN1: DR1206-33R-4/8; CAY16
TP1, TP2, TP3: TEST-PIN_0.9MM
TR1: SRF0703-821M; SRF0703
U$1: HR000002; CERT-SMALL-SILK
X1: 39-30-1020; MINIFIT_39301020
X2: 77317-104-28LF
ZD1: SMAJ51A; DO214AA

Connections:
!RESET: IC1.15 (B1); also elsewhere on the board
+3V3: C8.2, C17.2, C20.1, IC1.16 (VDD2), IC3.10 (EN2), IC3.16 (VDD2), IC5.5 (OUT), R11.2, TP3.1; also elsewhere on the board
+8V: C13.1, C21.2, IC5.1 (IN), IC5.3 (ON/!OFF), R4.1, TP1.1; also elsewhere on the board
+VAUX: X2.2
-8V: C5.1, R2.1, TP2.1; also elsewhere on the board
BOOT0: IC3.13 (B2); also elsewhere on the board
DC+: C1.2, L1.3 (1), R1.2, X1.1
DC-: C1.1, L1.1, R1.1, X1.2
DC_OUT+: C3.2, C6.1, C9.1, IC2.2 (VIN), L1.4 (2), R3.2, ZD1.C; also elsewhere on the board
DIB_A0: IC4.1 (A0), R14.2, X2.17
DIB_A1: IC4.2 (A1), R13.2, X2.19
DIB_A2: IC4.3 (A2), R12.2, X2.18
DIB_BOOT0: IC3.4 (A2), IC3.7 (EN1), X2.26
DIB_CSA: IC1.5 (A4), X2.9
DIB_CSB: DIB1.1.NO, X2.12
DIB_IRQ: DIB1.1.NC, X2.10
DIB_MISO: IC1.6 (A5), X2.14
DIB_MOSI: IC3.3 (A1), X2.15
DIB_NFAULT: X2.3
DIB_NRESET: IC1.2 (A1), X2.4
DIB_SCL: IC4.6 (SCL), X2.5
DIB_SCLK: IC1.4 (A3), X2.13
DIB_SDA: IC4.5 (SDA), X2.8
DIB_SYNC: IC1.3 (A2), X2.6
DIB_UART_RX: IC3.6 (A4), X2.27
DIB_UART_TX: IC3.5 (A3), X2.28
GND: C2.1, C4.2, C5.2, C6.2, C8.1, C9.2, C12.2, C13.2, C14.2, C15.1, C17.1, C18.1, C20.2, C21.1, C22.1, D2.A, IC1.9 (GND2), IC2.9 (GND), IC2.TP, IC3.9 (GND2_2), IC3.15 (GND2), IC5.2 (GND), L1.2, R5.1, R6.1, R8.1, R10.1, TR1.4, ZD1.A; also elsewhere on the board
GNDIO: C7.2, C16.2, C19.1, IC1.8 (GND1), IC3.2 (GND1_2), IC3.8 (GND1), IC4.4 (GND), IC4.7 (WP), X2.7, X2.11, X2.16, X2.20, X2.25
IRQ: IC1.10 (B6); also elsewhere on the board
MISO: IC1.11 (B5); also elsewhere on the board
MOSI: RN1.5 (2); also elsewhere on the board
unnamed: IC1.14 (B2), RN1.1
unnamed: IC1.13 (B3), RN1.2 (1)
unnamed: IC1.12 (B4), RN1.3 (1)
unnamed: IC3.14 (B1), RN1.4 (1)
unnamed: C22.2, IC5.4 (BYPASS)
unnamed: C4.1, D1.A, R2.2
unnamed: C11.2, R5.2
unnamed: IC2.3 (EN), R3.1, R6.2
unnamed: C14.1, IC2.4 (SS/TR)
unnamed: IC2.5 (RT/CLK), R8.2
unnamed: C15.2, IC2.8 (COMP), R9.2
unnamed: C18.2, R9.1
unnamed: C10.2, IC2.1 (BOOT)
unnamed: IC2.7 (VSENSE), R7.1, R10.2
unnamed: DIB1.1.COM, IC1.7 (A6)
NSS: RN1.6 (2); also elsewhere on the board
OE_SYNC: RN1.8 (2); also elsewhere on the board
PE: C2.2, C3.1, J1.1, J1.2; also elsewhere on the board
PH1: C10.1, C11.1, D2.C, IC2.10 (PH), TR1.1
PWRGOOD: IC2.6 (PWRGD); also elsewhere on the board
SCLK: RN1.7 (2); also elsewhere on the board
UART_RX: IC3.12 (B3); also elsewhere on the board
UART_TX: IC3.11 (B4), R11.1; also elsewhere on the board
V+: C7.1, C16.1, C19.2, IC1.1 (VDD1), IC3.1 (VDD1), IC4.8 (VCC), R12.1, R13.1, R14.1, X2.1
VOUT+: C12.1, R4.2, R7.2, TR1.3
VOUT-: D1.C, TR1.2

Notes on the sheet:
Licensed under the TAPR Open Hardware License (www.tapr.org/OHL)
Repository: https://github.com/eez-open
More info at http://www.envox.hr/eez
I2C Module ID EEPROM
Bias power supply, I2C EEPROM, digital isolators
Plastic parts
Bus isolator
+3V3 LDO
DIB v1.0 connector
Bias power supply
+48V DC input

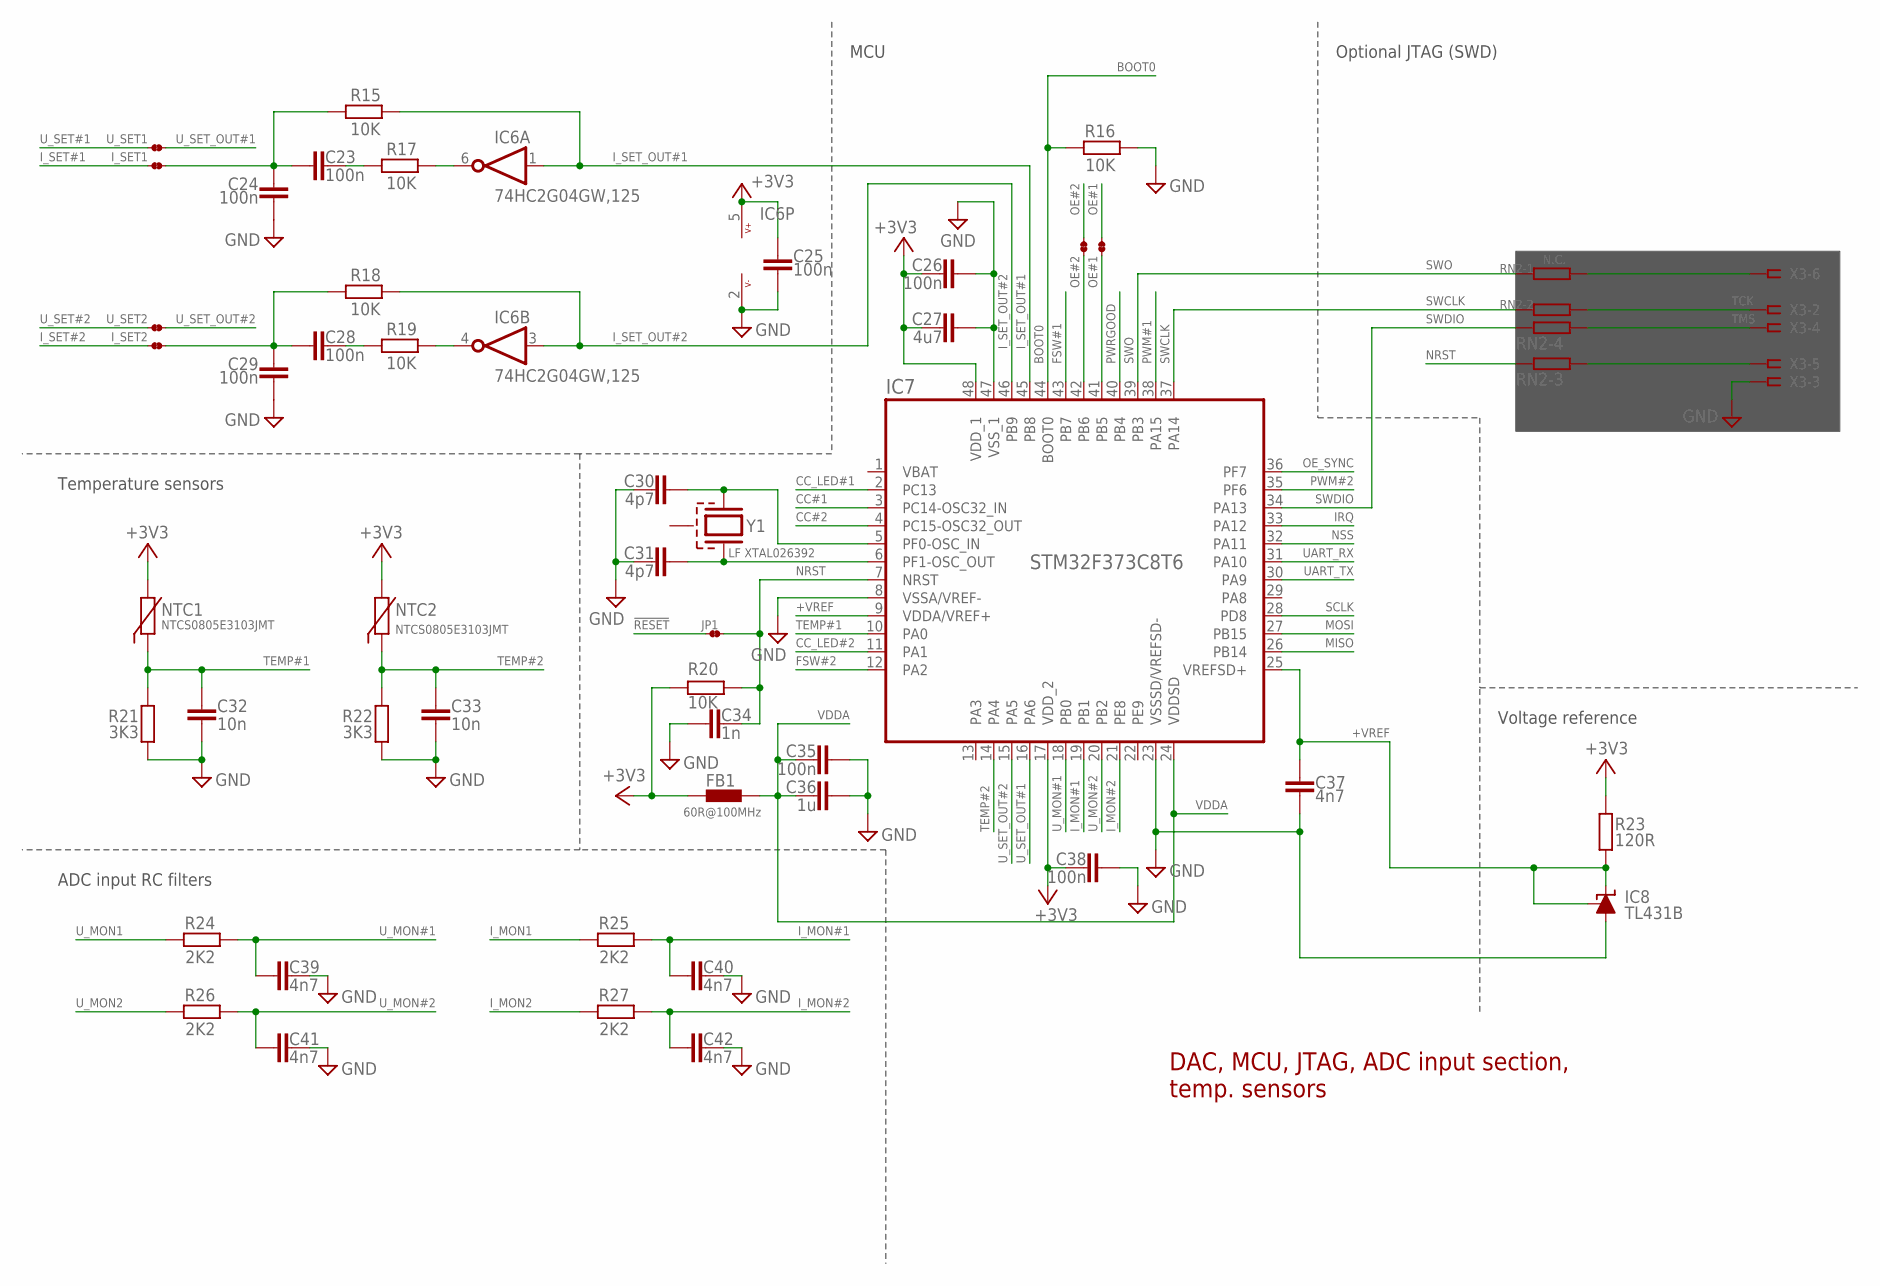
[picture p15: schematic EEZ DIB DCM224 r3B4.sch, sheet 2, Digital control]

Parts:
C23, C24, C25, C26, C28, C29, C35, C38: 100n; C0603
C27: 4u7; C1206
C30, C31: 4p7; C0603
C32, C33: 10n; C0805
C34: 1n; C0805
C36: 1u; C0805
C37, C39, C40, C41, C42: 4n7; C0805
FB1: 60R@100MHz; BEAD0603
IC6: 74HC2G04GW,125; SOT65P210X110-6N
IC7: STM32F373C8T6; LQFP-48
IC8: TL431B; SOT103P240X110-3N
I_SET1, I_SET2: JP2-NOCUT
JP1: JP2-NOCUT
NTC1, NTC2: NTCS0805E3103JMT; R_0805
OE#1, OE#2: JP2-NOCUT-0805; JP2-0805-NOCUT
R15, R16, R17, R18, R19, R20: 10K; R0805
R21, R22: 3K3; R0805
R23: 120R; R0805
R24, R25, R26, R27: 2K2; R0805
RN2: N.C.; CAY16
U_SET1, U_SET2: JP2-NOCUT
X3: N.C.; SSW-106-02-S-S
Y1: LF XTAL026392; 12SMX(B)

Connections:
!RESET: JP1.1; also elsewhere on the board
+3V3: C25.1, C26.2, C27.1, C38.2, FB1.P$1 (1), IC6.5 (V+), IC7.17 (VDD_2), IC7.48 (VDD_1), NTC1.1, NTC2.1, R20.1, R23.1; also elsewhere on the board
+VREF: C37.2, IC7.9 (VDDA/VREF+), IC7.25 (VREFSD+), IC8.1 (C), IC8.2 (R), R23.2
BOOT0: IC7.44 (BOOT0), R16.2; also elsewhere on the board
CC#1: IC7.3 (PC14-OSC32_IN); also elsewhere on the board
CC#2: IC7.4 (PC15-OSC32_OUT); also elsewhere on the board
CC_LED#1: IC7.2 (PC13); also elsewhere on the board
CC_LED#2: IC7.11 (PA1); also elsewhere on the board
FSW#1: IC7.43 (PB7); also elsewhere on the board
FSW#2: IC7.12 (PA2); also elsewhere on the board
GND: C24.2, C25.2, C26.1, C27.2, C29.2, C30.1, C31.1, C32.1, C33.1, C34.2, C35.1, C36.1, C37.1, C38.1, C39.1, C40.1, C41.1, C42.1, IC6.2 (V-), IC7.8 (VSSA/VREF-), IC7.23 (VSSSD/VREFSD-), IC7.47 (VSS_1), IC8.3 (A), R16.1, R21.2, R22.2, X3.3; also elsewhere on the board
IRQ: IC7.33 (PA12); also elsewhere on the board
I_MON1: R25.2; also elsewhere on the board
I_MON2: R27.2; also elsewhere on the board
I_MON#1: C40.2, IC7.19 (PB1), R25.1
I_MON#2: C42.2, IC7.21 (PE8), R27.1
I_SET#1: I_SET1.1; also elsewhere on the board
I_SET#2: I_SET2.1; also elsewhere on the board
I_SET_OUT#1: IC6.1 (I), IC7.45 (PB8), R15.2
I_SET_OUT#2: IC6.3 (I), IC7.46 (PB9), R18.2
MISO: IC7.26 (PB14); also elsewhere on the board
MOSI: IC7.27 (PB15); also elsewhere on the board
unnamed: C28.2, R19.1
unnamed: C28.1, C29.1, I_SET2.2, R18.1
unnamed: IC6.4 (O), R19.2
unnamed: RN2.8 (2), X3.6
unnamed: RN2.6 (2), X3.5
unnamed: C23.2, R17.1
unnamed: C23.1, C24.1, I_SET1.2, R15.1
unnamed: IC6.6 (O), R17.2
unnamed: IC7.42 (PB6), OE#2.1
unnamed: IC7.41 (PB5), OE#1.1
NRST: C34.1, IC7.7 (NRST), JP1.2, R20.2, RN2.3 (1)
NSS: IC7.32 (PA11); also elsewhere on the board
OE#1: OE#1.2; also elsewhere on the board
OE#2: OE#2.2; also elsewhere on the board
OE_SYNC: IC7.36 (PF7); also elsewhere on the board
PWM#1: IC7.38 (PA15); also elsewhere on the board
PWM#2: IC7.35 (PF6); also elsewhere on the board
PWRGOOD: IC7.40 (PB4); also elsewhere on the board
RCC_OSC_IN: C30.2, IC7.5 (PF0-OSC_IN), Y1.3 (2)
RCC_OSC_OUT: C31.2, IC7.6 (PF1-OSC_OUT), Y1.1
SCLK: IC7.28 (PD8); also elsewhere on the board
SWCLK: IC7.37 (PA14), RN2.2 (1)
SWDIO: IC7.34 (PA13), RN2.4 (1)
SWO: IC7.39 (PB3), RN2.1
TCK: RN2.7 (2), X3.2
TEMP#1: C32.2, IC7.10 (PA0), NTC1.2, R21.1
TEMP#2: C33.2, IC7.14 (PA4), NTC2.2, R22.1
TMS: RN2.5 (2), X3.4
UART_RX: IC7.31 (PA10); also elsewhere on the board
UART_TX: IC7.30 (PA9); also elsewhere on the board
U_MON1: R24.2; also elsewhere on the board
U_MON2: R26.2; also elsewhere on the board
U_MON#1: C39.2, IC7.18 (PB0), R24.1
U_MON#2: C41.2, IC7.20 (PB2), R26.1
U_SET#1: U_SET1.1; also elsewhere on the board
U_SET#2: U_SET2.1; also elsewhere on the board
U_SET_OUT#1: IC7.16 (PA6), U_SET1.2
U_SET_OUT#2: IC7.15 (PA5), U_SET2.2
VDDA: C35.2, C36.2, FB1.P$2 (2), IC7.24 (VDDSD)

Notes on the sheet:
DAC, MCU, JTAG, ADC input section, temp. sensors
Optional JTAG (SWD)
MCU
Temperature sensors
ADC input RC filters
Voltage reference

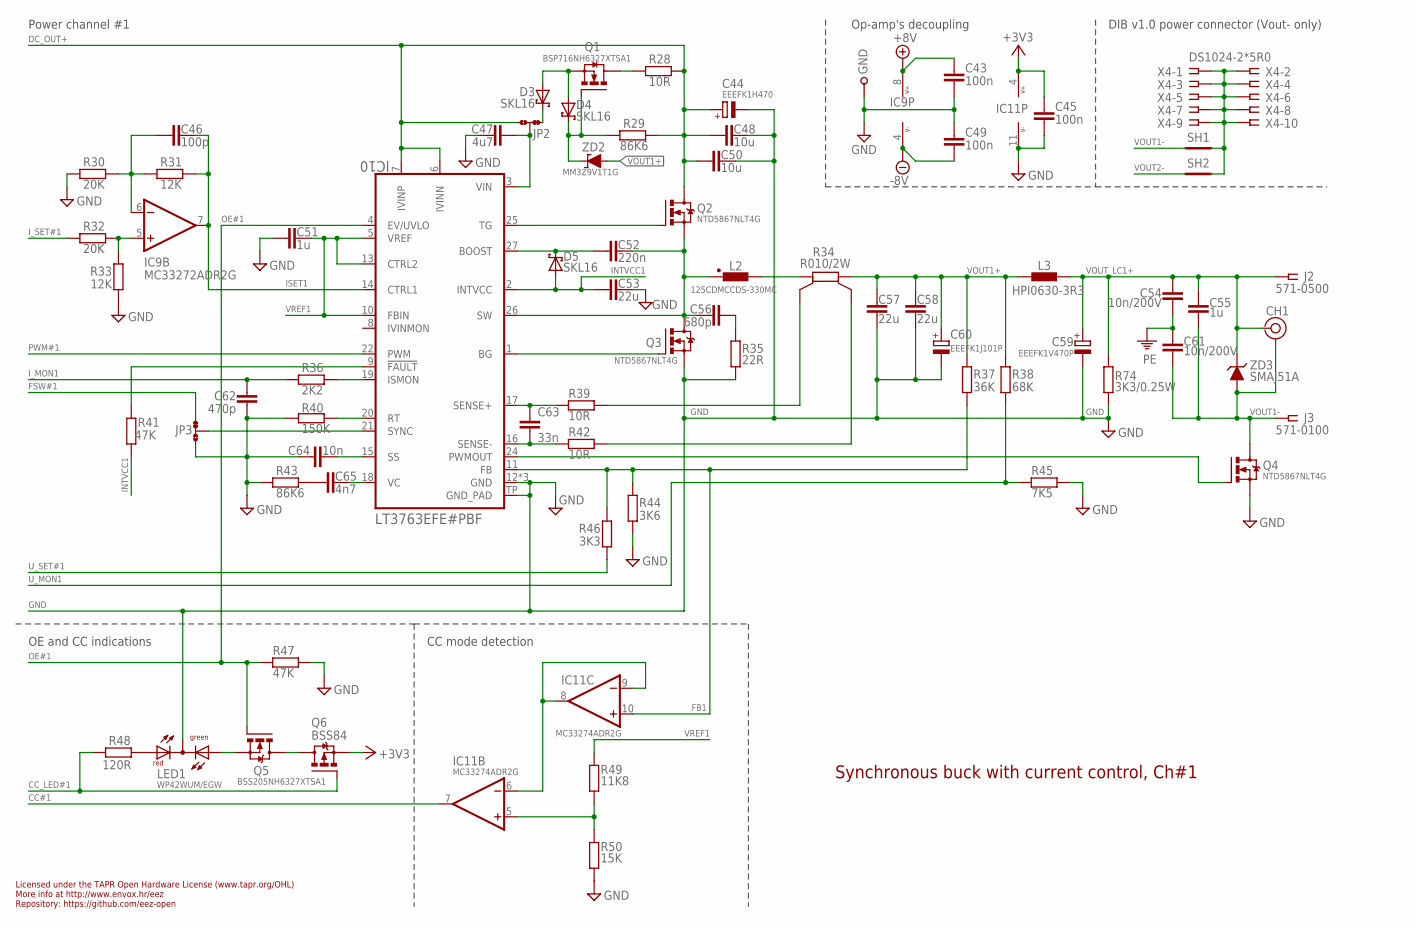
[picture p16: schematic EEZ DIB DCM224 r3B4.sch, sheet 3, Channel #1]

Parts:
C43, C45, C49: 100n; C0603
C44: EEEFK1H470; CAPAE830X1050N
C46: 100p; C0805
C47: 4u7; C1206
C48, C50: 10u; C1210
C51, C55: 1u; C0805
C52: 220n; C0805
C53: 22u; C1206
C54, C61: 10n/200V; C1206
C56: 680p; C0805
C57, C58: 22u; C1210
C59: EEEFK1V470P; CAPAE660X610N
C60: EEEFK1J101P; CAPAE1030X1050N
C62: 470p; C0805
C63: 33n; C0805
C64: 10n; C0805
C65: 4n7; C0805
CH1: TEST_POINT-2; TP_1.1MM_2
D3, D4, D5: SKL16; SOD123
GND: TEST-PIN_0.9MM
IC9: MC33272ADR2G; SOIC127P600X173-8N
IC10: LT3763EFE#PBF; LTC_05-08-1663-EB
IC11: MC33274ADR2G; SOIC127P600X175-14N
J2: 571-0500; DELTRON_571
J3: 571-0100; DELTRON_571
JP2, JP3: JP3-CUT-0805-ROTATED; JP3-0805-CUT2
L2: 125CDMCCDS-330MC; 125CDMCC/DS
L3: HPI0630-3R3; COILCRAFT_HPI0630
LED1: WP42WUM/EGW; L-42WUM-1EGWT
Q1: BSP716NH6327XTSA1; SOT223
Q2, Q3, Q4: NTD5867NLT4G; TO252
Q5: BSS205NH6327XTSA1; SOT103P240X110-3N
Q6: BSS84; SOT95P237X112-3N
R28, R39, R42: 10R; R0805
R29, R43: 86K6; R0805
R30, R32: 20K; R0805
R31, R33: 12K; R0805
R34: R010/2W; R_2512-4WIRE
R35: 22R; R1206
R36: 2K2; R0805
R37: 36K; R0805
R38: 68K; R0805
R40: 150K; R0805
R41, R47: 47K; R0805
R44: 3K6; R0805
R45: 7K5; R0805
R46: 3K3; R0805
R48: 120R; R0805
R49: 11K8; R0805
R50: 15K; R0805
R74: 3K3/0.25W; R1206
SH1, SH2: SHORTNOHOLE; SHORT_NOHOLE
X4: DS1024-2*5R0; SSW-105-02-T-D-RA
ZD2: MM3Z9V1T1G; SOD323-W
ZD3: SMAJ51A; DO214AA

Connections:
+3V3: C45.1, IC11.4 (V+), Q6.2 (S); also elsewhere on the board
+8V: C43.1, IC9.8 (V+); also elsewhere on the board
-8V: C49.2, IC9.4 (V-); also elsewhere on the board
BG1: IC10.1 (BG), Q3.1 (G)
CC#1: IC11.7 (OUT); also elsewhere on the board
CC_LED#1: Q6.1 (G), R48.2; also elsewhere on the board
DC_OUT+: C44.+, C48.1, C50.1, IC10.6 (IVINN), IC10.7 (IVINP), JP2.NO, Q2.3 (D), R28.1, R29.1; also elsewhere on the board
FB1: IC10.11 (FB), IC11.10 (+IN), R37.1, R44.2, R46.2
FSW#1: JP3.NC; also elsewhere on the board
GND: C43.2, C44.-, C45.2, C47.2, C48.2, C49.1, C50.2, C51.2, C53.2, C57.2, C58.2, C59.2 (-), C60.-, C62.1, C64.1, GND.1, IC10.12 (GND), IC10.23 (GND), IC10.28 (GND), IC10.TP (GND_PAD), IC11.11 (V-), JP3.NO, LED1.CC (C), Q3.2 (S), Q4.2 (S), R30.1, R33.1, R35.1, R40.1, R43.1, R44.1, R45.1, R47.2, R50.1, R74.1; also elsewhere on the board
INTVCC1: C53.1, D5.A, IC10.2 (INTVCC), R41.2
ISET1: C46.1, IC9.7 (OUT), IC10.14 (CTRL1), R31.2
I_MON1: C62.2, R36.1; also elsewhere on the board
I_SET#1: R32.1; also elsewhere on the board
LOUT1: L2.2, R34.1
unnamed: IC10.21 (SYNC), JP3.COM
unnamed: D3.C, JP2.NC
unnamed: Q5.3 (D), Q6.3 (D)
unnamed: R34.1S, R39.2
unnamed: IC10.20 (RT), R40.2
unnamed: LED1.RED (AR), R48.1
unnamed: C64.2, IC10.15 (SS)
unnamed: C65.1, R43.2
unnamed: C65.2, IC10.18 (VC)
unnamed: R34.2S, R42.2
unnamed: C56.2, R35.2
unnamed: IC10.9 (!FAULT), R41.1
unnamed: C52.1, D5.C, IC10.27 (BOOST)
unnamed: D4.C, Q1.1 (G), R29.2, ZD2.C
unnamed: LED1.GREEN (AG), Q5.2 (S)
unnamed: C47.1, IC10.3 (VIN), JP2.COM
unnamed: D3.A, D4.A, Q1.3 (S)
unnamed: IC10.19 (ISMON), R36.2
unnamed: SH1.2 (GND_B), SH2.2 (GND_B), X4.1, X4.2, X4.3, X4.4, X4.5, X4.6, X4.7, X4.8, X4.9, X4.10
unnamed: IC11.5 (+IN), R49.1, R50.2
unnamed: IC11.6 (-IN), IC11.8 (OUT), IC11.9 (-IN)
unnamed: IC9.5 (+IN), R32.2, R33.2
unnamed: C46.2, IC9.6 (-IN), R30.2, R31.1
unnamed: IC10.24 (PWMOUT), Q4.1 (G)
OE#1: IC10.4 (EV/UVLO), Q5.1 (G), R47.1; also elsewhere on the board
PE: C54.1, C61.1; also elsewhere on the board
PWM#1: IC10.22 (PWM); also elsewhere on the board
Q1D: Q1.2 (D), Q1.4 (D), R28.2
SENSE1+: C63.1, IC10.17 (SENSE+), R39.1
SENSE1-: C63.2, IC10.16 (SENSE-), R42.1
SW1: C52.2, C56.1, IC10.26 (SW), L2.1, Q2.2 (S), Q3.3 (D)
TG1: IC10.25 (TG), Q2.1 (G)
U_MON1: R38.1, R45.2; also elsewhere on the board
U_SET#1: R46.1; also elsewhere on the board
VOUT1+: C57.1, C58.1, C60.+, L3.1, R34.2, R37.2, R38.2, ZD2.A
VOUT1-: C55.2, C61.2, CH1.GND, J3.1, J3.1.1, Q4.3 (D), SH1.1 (GND_A), ZD3.A
VOUT2-: SH2.1 (GND_A); also elsewhere on the board
VOUT_LC1+: C54.2, C55.1, C59.1 (+), CH1.TIP, J2.1, J2.1.1, L3.2, R74.2, ZD3.C
VREF1: C51.1, IC10.5 (VREF), IC10.10 (FBIN), IC10.13 (CTRL2), R49.2

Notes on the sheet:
Licensed under the TAPR Open Hardware License (www.tapr.org/OHL)
Repository: https://github.com/eez-open
More info at http://www.envox.hr/eez
Power channel #1
CC mode detection
DIB v1.0 power connector (Vout- only)
Op-amp's decoupling
OE and CC indications
Synchronous buck with current control, Ch#1

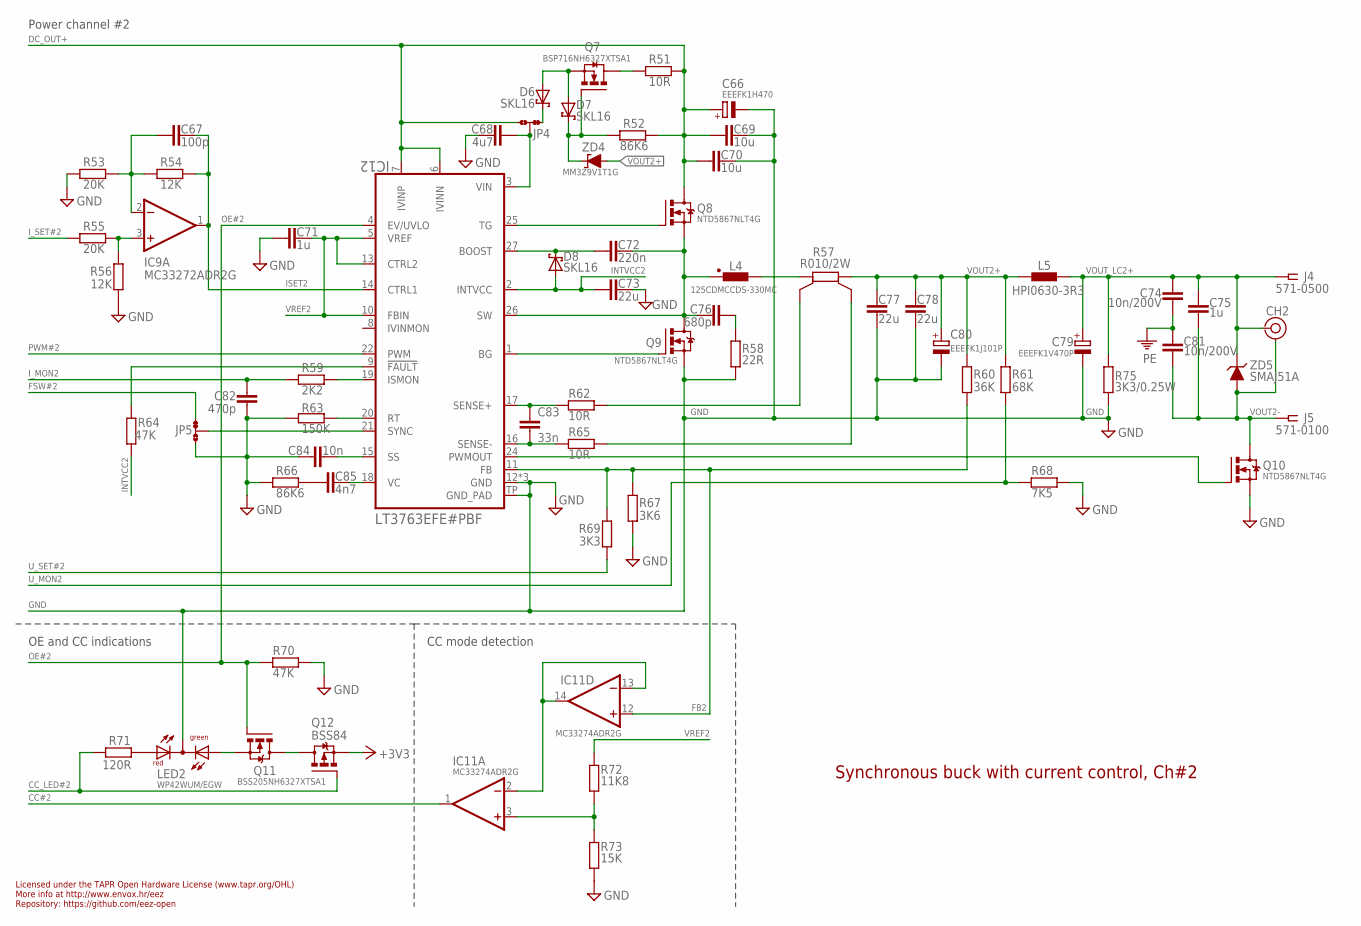
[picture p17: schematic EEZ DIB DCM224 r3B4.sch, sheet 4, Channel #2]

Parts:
C66: EEEFK1H470; CAPAE830X1050N
C67: 100p; C0805
C68: 4u7; C1206
C69, C70: 10u; C1210
C71, C75: 1u; C0805
C72: 220n; C0805
C73: 22u; C1206
C74, C81: 10n/200V; C1206
C76: 680p; C0805
C77, C78: 22u; C1210
C79: EEEFK1V470P; CAPAE660X610N
C80: EEEFK1J101P; CAPAE1030X1050N
C82: 470p; C0805
C83: 33n; C0805
C84: 10n; C0805
C85: 4n7; C0805
CH2: TEST_POINT-2; TP_1.1MM_2
D6, D7, D8: SKL16; SOD123
IC9: MC33272ADR2G; SOIC127P600X173-8N
IC11: MC33274ADR2G; SOIC127P600X175-14N
IC12: LT3763EFE#PBF; LTC_05-08-1663-EB
J4: 571-0500; DELTRON_571
J5: 571-0100; DELTRON_571
JP4, JP5: JP3-CUT-0805-ROTATED; JP3-0805-CUT2
L4: 125CDMCCDS-330MC; 125CDMCC/DS
L5: HPI0630-3R3; COILCRAFT_HPI0630
LED2: WP42WUM/EGW; L-42WUM-1EGWT
Q7: BSP716NH6327XTSA1; SOT223
Q8, Q9, Q10: NTD5867NLT4G; TO252
Q11: BSS205NH6327XTSA1; SOT103P240X110-3N
Q12: BSS84; SOT95P237X112-3N
R51, R62, R65: 10R; R0805
R52, R66: 86K6; R0805
R53, R55: 20K; R0805
R54, R56: 12K; R0805
R57: R010/2W; R_2512-4WIRE
R58: 22R; R1206
R59: 2K2; R0805
R60: 36K; R0805
R61: 68K; R0805
R63: 150K; R0805
R64, R70: 47K; R0805
R67: 3K6; R0805
R68: 7K5; R0805
R69: 3K3; R0805
R71: 120R; R0805
R72: 11K8; R0805
R73: 15K; R0805
R75: 3K3/0.25W; R1206
ZD4: MM3Z9V1T1G; SOD323-W
ZD5: SMAJ51A; DO214AA

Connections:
+3V3: Q12.2 (S); also elsewhere on the board
BG2: IC12.1 (BG), Q9.1 (G)
CC#2: IC11.1 (OUT); also elsewhere on the board
CC_LED#2: Q12.1 (G), R71.2; also elsewhere on the board
DC_OUT+: C66.+, C69.1, C70.1, IC12.6 (IVINN), IC12.7 (IVINP), JP4.NO, Q8.3 (D), R51.1, R52.1; also elsewhere on the board
FB2: IC11.12 (+IN), IC12.11 (FB), R60.1, R67.2, R69.2
FSW#2: JP5.NC; also elsewhere on the board
GND: C66.-, C68.2, C69.2, C70.2, C71.2, C73.2, C77.2, C78.2, C79.2 (-), C80.-, C82.1, C84.1, IC12.12 (GND), IC12.23 (GND), IC12.28 (GND), IC12.TP (GND_PAD), JP5.NO, LED2.CC (C), Q9.2 (S), Q10.2 (S), R53.1, R56.1, R58.1, R63.1, R66.1, R67.1, R68.1, R70.2, R73.1, R75.1; also elsewhere on the board
INTVCC2: C73.1, D8.A, IC12.2 (INTVCC), R64.2
ISET2: C67.1, IC9.1 (OUT), IC12.14 (CTRL1), R54.2
I_MON2: C82.2, R59.1; also elsewhere on the board
I_SET#2: R55.1; also elsewhere on the board
LOUT2: L4.2, R57.1
unnamed: LED2.RED (AR), R71.1
unnamed: IC12.21 (SYNC), JP5.COM
unnamed: IC12.20 (RT), R63.2
unnamed: C84.2, IC12.15 (SS)
unnamed: C85.1, R66.2
unnamed: C85.2, IC12.18 (VC)
unnamed: IC12.9 (!FAULT), R64.1
unnamed: R57.1S, R62.2
unnamed: R57.2S, R65.2
unnamed: C76.2, R58.2
unnamed: C72.1, D8.C, IC12.27 (BOOST)
unnamed: IC12.19 (ISMON), R59.2
unnamed: Q11.3 (D), Q12.3 (D)
unnamed: LED2.GREEN (AG), Q11.2 (S)
unnamed: D7.C, Q7.1 (G), R52.2, ZD4.C
unnamed: C68.1, IC12.3 (VIN), JP4.COM
unnamed: D6.A, D7.A, Q7.3 (S)
unnamed: D6.C, JP4.NC
unnamed: IC11.2 (-IN), IC11.13 (-IN), IC11.14 (OUT)
unnamed: IC11.3 (+IN), R72.1, R73.2
unnamed: C67.2, IC9.2 (-IN), R53.2, R54.1
unnamed: IC9.3 (+IN), R55.2, R56.2
unnamed: IC12.24 (PWMOUT), Q10.1 (G)
OE#2: IC12.4 (EV/UVLO), Q11.1 (G), R70.1; also elsewhere on the board
PE: C74.1, C81.1; also elsewhere on the board
PWM#2: IC12.22 (PWM); also elsewhere on the board
Q1D1: Q7.2 (D), Q7.4 (D), R51.2
SENSE1+1: C83.1, IC12.17 (SENSE+), R62.1
SENSE1-1: C83.2, IC12.16 (SENSE-), R65.1
SW2: C72.2, C76.1, IC12.26 (SW), L4.1, Q8.2 (S), Q9.3 (D)
TG2: IC12.25 (TG), Q8.1 (G)
U_MON2: R61.1, R68.2; also elsewhere on the board
U_SET#2: R69.1; also elsewhere on the board
VOUT2+: C77.1, C78.1, C80.+, L5.1, R57.2, R60.2, R61.2, ZD4.A
VOUT2-: C75.2, C81.2, CH2.GND, J5.1, J5.1.1, Q10.3 (D), ZD5.A; also elsewhere on the board
VOUT_LC2+: C74.2, C75.1, C79.1 (+), CH2.TIP, J4.1, J4.1.1, L5.2, R75.2, ZD5.C
VREF2: C71.1, IC12.5 (VREF), IC12.10 (FBIN), IC12.13 (CTRL2), R72.2

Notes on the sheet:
Licensed under the TAPR Open Hardware License (www.tapr.org/OHL)
Repository: https://github.com/eez-open
More info at http://www.envox.hr/eez
CC mode detection
OE and CC indications
Power channel #2
Synchronous buck with current control, Ch#2

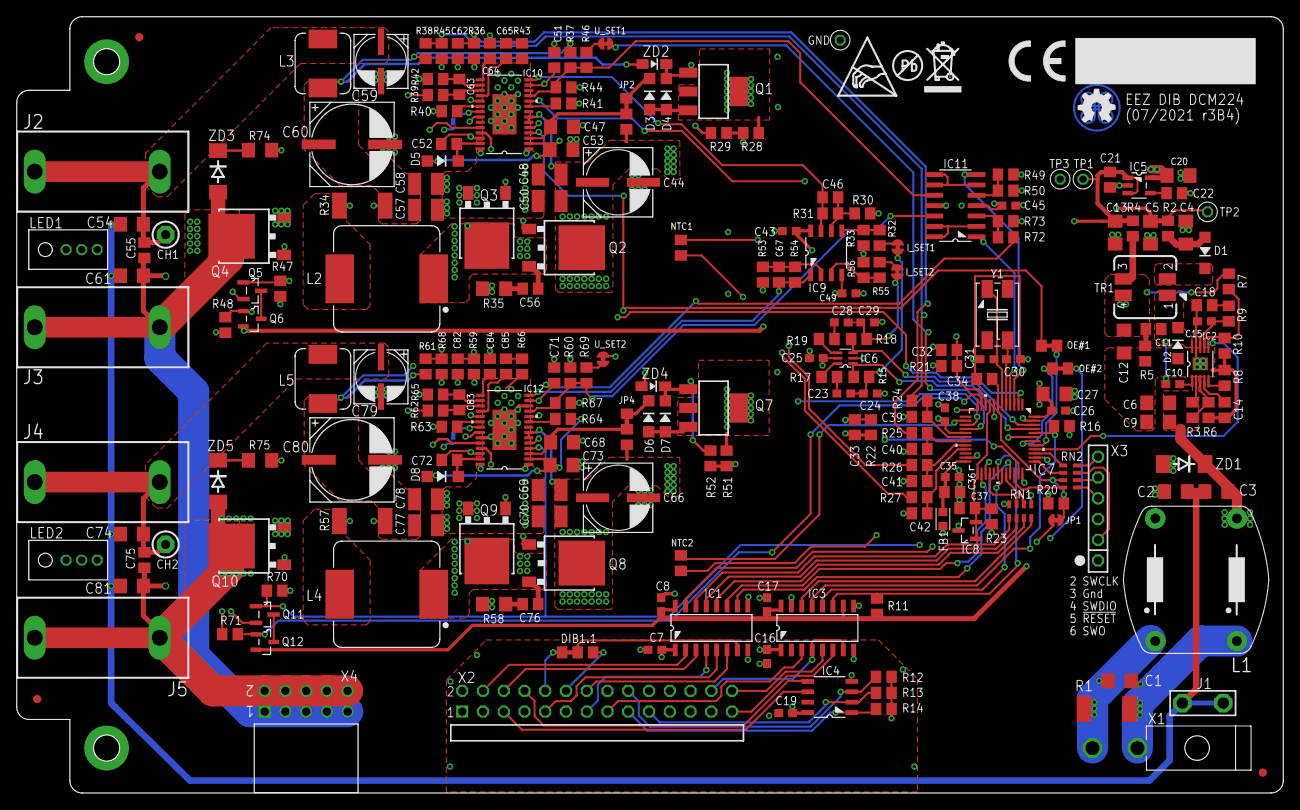
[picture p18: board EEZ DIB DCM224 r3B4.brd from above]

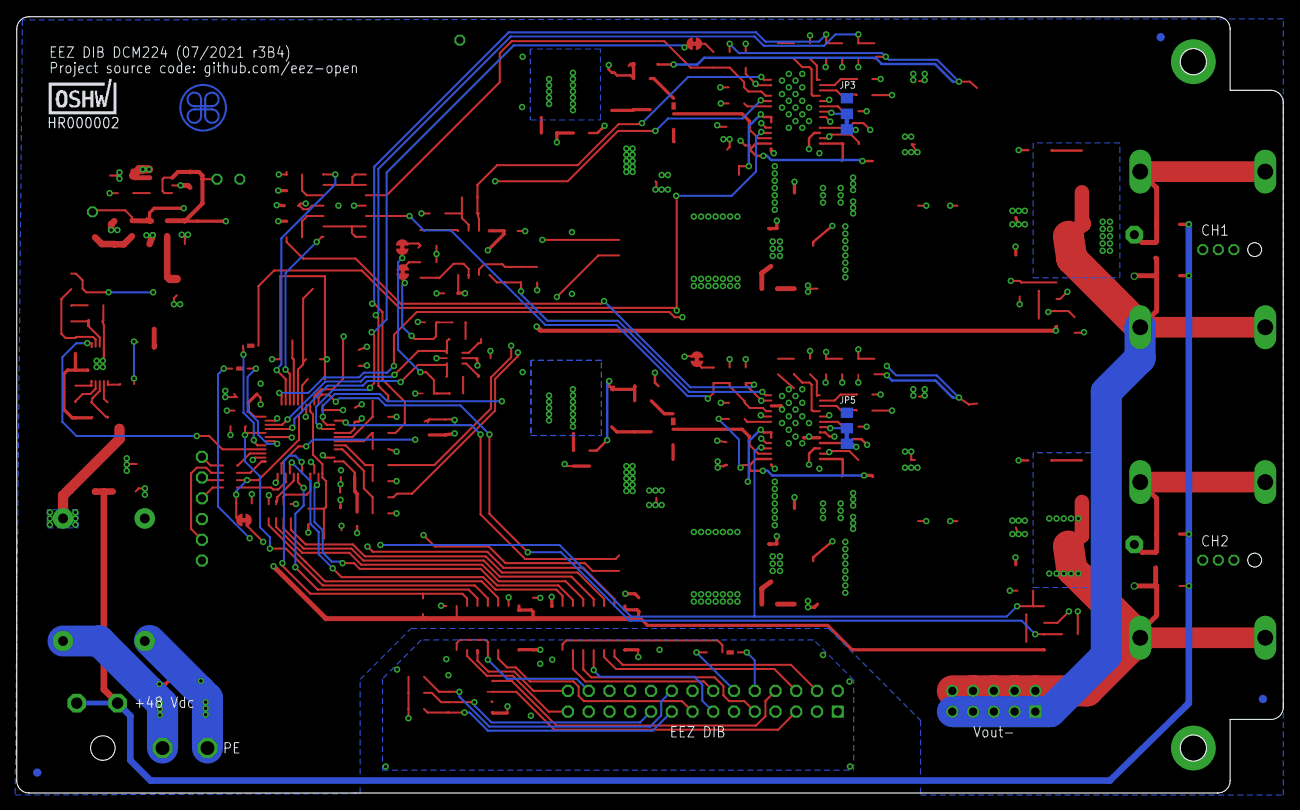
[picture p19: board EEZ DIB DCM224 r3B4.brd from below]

Board: 4 copper layers, 155.0 x 95.0 mm, 251 parts (4 on the bottom side), 178 nets.

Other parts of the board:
EEZ_SIGNATURE: SIGNATURESMALL; SIGNATURE_5MM
U$2: RECYCLE_BIN1/8
U$3: CE_5MM
U$4: ESD_SYMBOL
U$7: PB_SMALL

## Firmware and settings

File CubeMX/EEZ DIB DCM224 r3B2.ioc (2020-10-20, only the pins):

Mcu.UserName=STM32F373C8Tx
PA0.GPIO_Label=TEMP\#1
PA0.Signal=ADC1_IN0
PA1.GPIO_Label=CC_LED\#2
PA1.Signal=GPIO_Output
PA10.Signal=USART1_RX
PA11.GPIO_Label=DIB_CSA
PA11.Signal=SPI2_NSS
PA12.GPIO_Label=DIB_IRQ
PA12.Signal=GPIO_Output
PA13.Signal=SYS_JTMS-SWDIO
PA14.Signal=SYS_JTCK-SWCLK
PA15.GPIO_Label=PWM\#1
PA15.Signal=GPIO_Output
PA2.GPIO_Label=FSW\#2
PA2.Signal=S_TIM19_CH3
PA4.GPIO_Label=TEMP\#2
PA4.Signal=ADC1_IN4
PA5.GPIO_Label=U_SET\#2
PA5.Signal=COMP_DAC12_group
PA6.GPIO_Label=U_SET\#1
PA6.Signal=COMP_DAC21_group
PA9.Signal=USART1_TX
PB0.GPIO_Label=U_MON\#1
PB0.Signal=SDADC1_AIN6P
PB1.GPIO_Label=I_MON\#1
PB1.Signal=SDADC1_AIN5P
PB14.GPIO_Label=DIB_MISO
PB14.Signal=SPI2_MISO
PB15.GPIO_Label=DIB_MOSI
PB15.Signal=SPI2_MOSI
PB2.GPIO_Label=U_MON\#2
PB2.Signal=SDADC1_AIN4P
PB3.Signal=SYS_JTDO-TRACESWO
PB4.GPIO_Label=PWRGOOD
PB4.Signal=GPXTI4
PB5.GPIO_Label=OE\#1
PB5.Signal=GPIO_Output
PB6.GPIO_Label=OE\#2
PB6.Signal=GPIO_Output
PB7.GPIO_Label=FSW\#1
PB7.Signal=S_TIM19_CH2
PB8.GPIO_Label=I_SET\#1
PB8.Signal=S_TIM16_CH1
PB9.GPIO_Label=I_SET\#2
PB9.Signal=S_TIM17_CH1
PC13.GPIO_Label=CC_LED\#1
PC13.Signal=GPIO_Output
PC14-OSC32_IN.GPIO_Label=CC\#1
PC14-OSC32_IN.Signal=GPXTI14
PC15-OSC32_OUT.GPIO_Label=CC\#2
PC15-OSC32_OUT.Signal=GPXTI15
PD8.GPIO_Label=DIB_SCK
PD8.Signal=SPI2_SCK
PE8.GPIO_Label=I_MON\#2
PE8.Signal=SDADC1_AIN8P
PF6.GPIO_Label=PWM\#2
PF6.Signal=GPIO_Output
PF7.GPIO_Label=DIB_SYNC
PF7.Signal=GPXTI7

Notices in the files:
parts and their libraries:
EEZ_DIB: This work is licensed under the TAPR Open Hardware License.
